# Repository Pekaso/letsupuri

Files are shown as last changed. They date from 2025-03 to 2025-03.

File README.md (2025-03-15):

# れつぷり!! letsupuri keyboard



48キー左右分離型キーボード「Let's Split」のリメイク版。

A remake of the 48 key split keyboard "Let's Split".
Left and right connection is using USB Type-C cable. And main and power circult are separated.

- 左右間をUSB-Cケーブルで接続
- PCBはメイン基板と電源基板で分離
- シリコン製ショックアブソーバーを使ったマウント

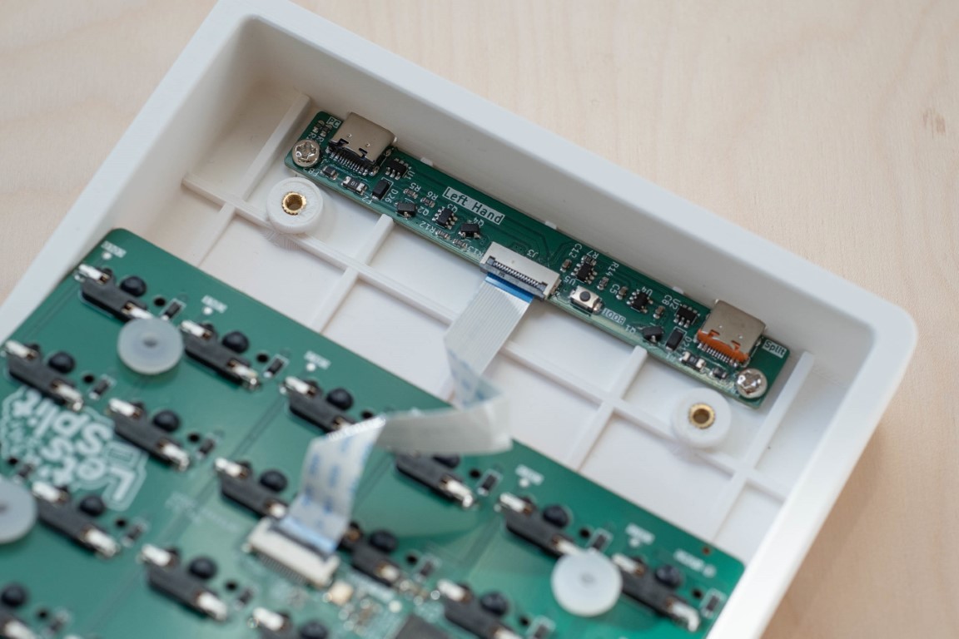
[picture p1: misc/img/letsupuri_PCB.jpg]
feature


## ビルドガイド Build Guide

- ロープロファイル版ビルドガイド(日本語版): [Low Profile Ver. Build Guide (JP)](misc/buildguide/buildguide_lowprofile_jp.md)

れつぷり!!にはCherry MX版とLow Profile版があります。ハードウェアのメイン基板はCherry MX版（PCB_main_MX）とLow Profile版（PCB_main_lowprofile）で分かれています。電源基板（PCB_power）は共通です。

"れつぷり!!" has the Cherry MX version and the Low Profile version. The main board of the hardware is divided into the Cherry MX version (PCB_main_MX) and the Low Profile version (PCB_main_lowprofile). The power supply board (PCB_power) is the same for both versions.

> [!WARNING]
> Cherry MX版のハードウェア(PCB_main_MX)は現在のところ正しく動きません。The Cherry MX version (PCB_main_MX) does not currently work properly.

## ぴくちゃ
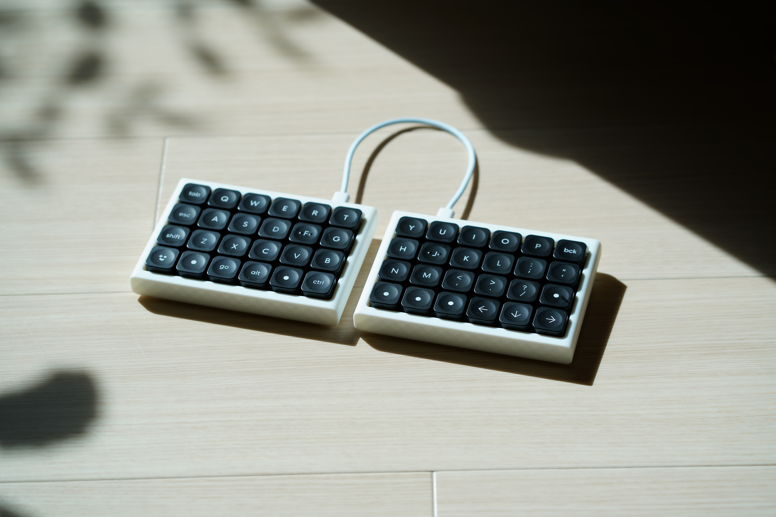
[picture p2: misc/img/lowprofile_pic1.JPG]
れつぷり!!LowProfile版

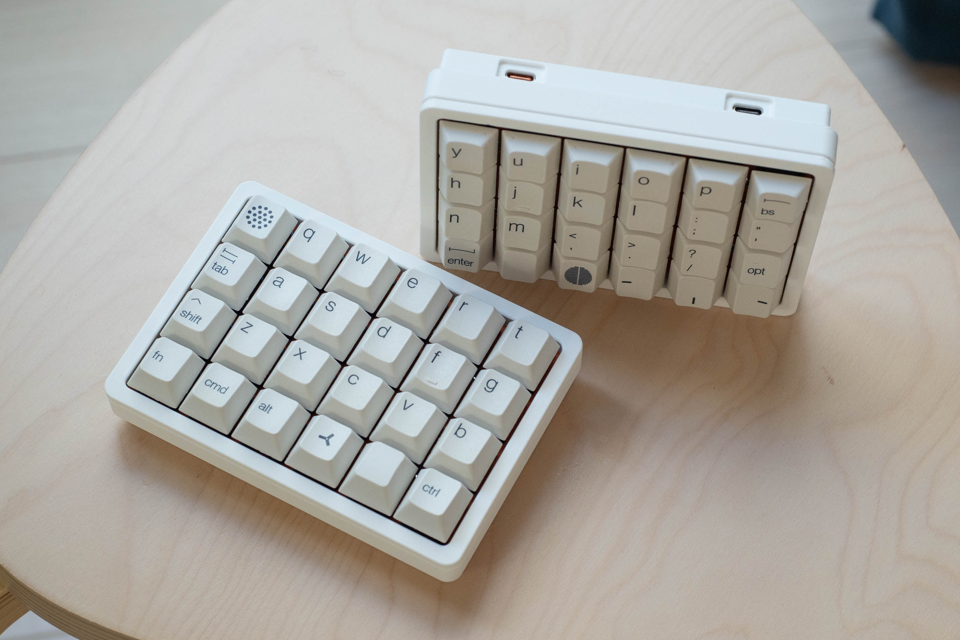
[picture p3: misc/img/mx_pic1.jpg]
れつぷり!!MX版


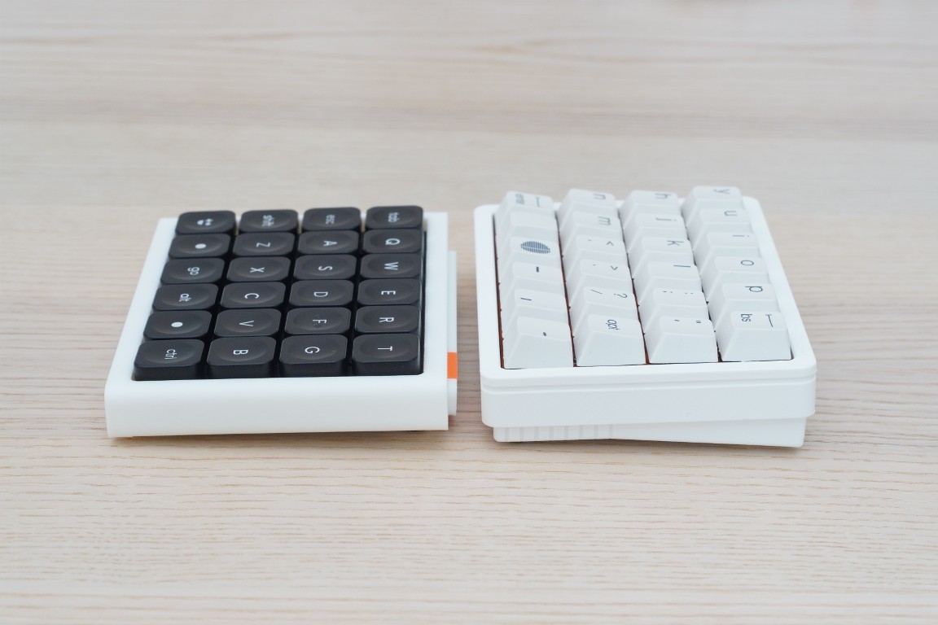
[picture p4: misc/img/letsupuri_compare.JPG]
れつぷり!!LowProfile版（左）とMX版（右）の比較


more detail at [pekaso.org](https://pekaso.org)

# License
This repository contains both hardware and firmware components, each under a different license.

- `hardware/`: Licensed under the MIT License
- `firmware/`: Licensed under the GPL License (inherited from the original repository)

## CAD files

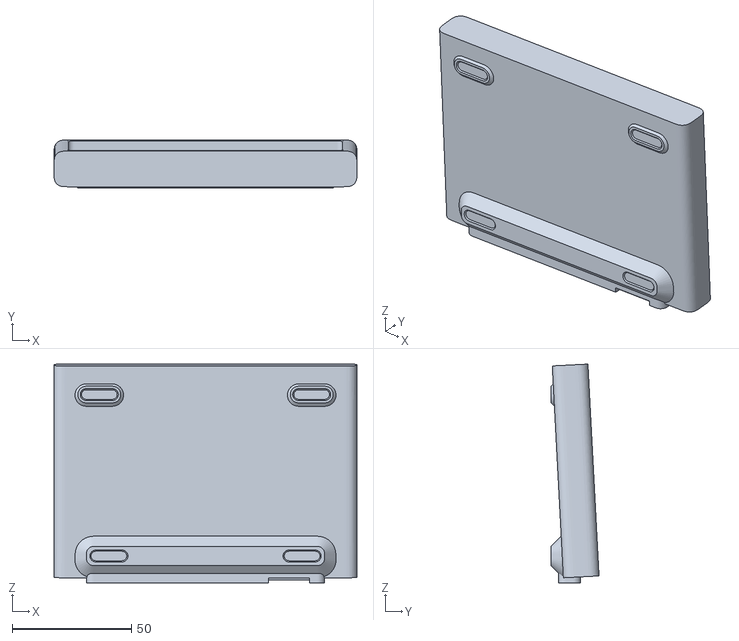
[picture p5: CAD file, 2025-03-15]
hardware/CASE/lowprofile_main.stl
127.1 x 20.2 x 91.8

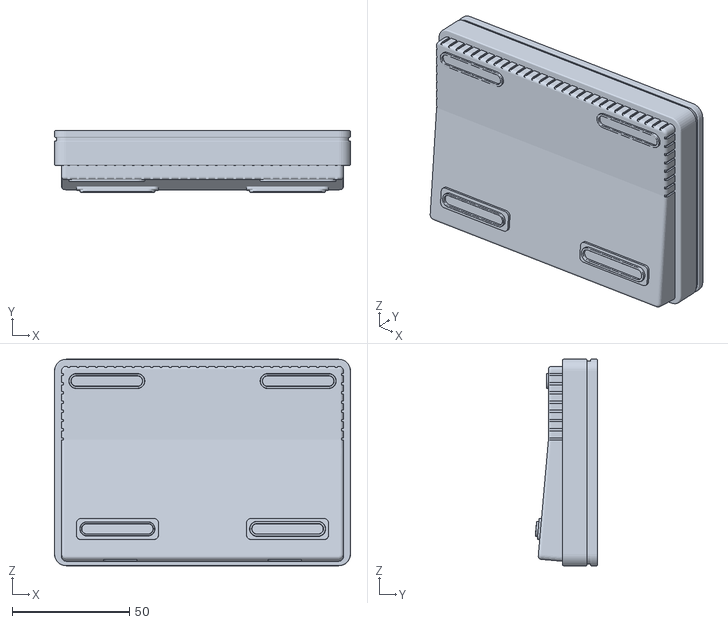
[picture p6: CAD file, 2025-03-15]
hardware/CASE/MX_main.stl
126.1 x 26.6 x 88.0

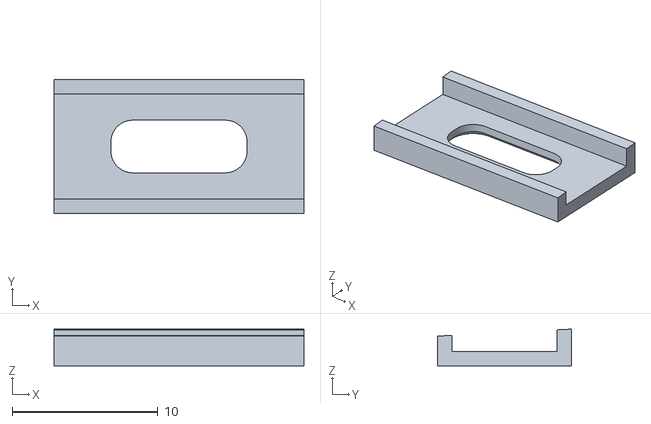
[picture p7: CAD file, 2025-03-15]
hardware/CASE/lowprofile_badge.stl
17.1 x 9.21 x 2.53

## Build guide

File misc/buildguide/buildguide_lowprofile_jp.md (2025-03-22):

# れつぷり!! Low Profile版 キット ビルドガイド

## はじめに

キットをお選びいただきありがとうございます。
組み立て前にビルドガイドと付属品リストを確認し、不足があれば連絡先までご連絡ください。

## 付属品

| 項目 | 数量 |
|---|---|
| 3Dプリントケース（試供品） | 2組 |
| れつぷり!!基板（ケースに組込済み） | 2組 |
| プレート（ケースに組込済み） | 2個 |
| ネジ（M2x8mm, ケースに組込済み） | 8個 |
| ネジ（M3x4mm, ケースに組込済み） | 4個 |
| その他（ステッカー） | 1式 |

## 購入が必要なもの

| 項目 | 数量 |
|---|---|
| キースイッチ（Choc V1/Choc V2※1） | 48個 |
| キーキャップ（スイッチに合わせたもの） | 48個 |
| USB Type-Cケーブル（左右接続用） | 1本 |
| USB Type-Cケーブル（PC接続用） | 1本 |
| ドライバー（0番） | 1本 |
| はんだごて（オプション※2） | 1式 |
| テスター（オプション※2） | 1式 |

> [!NOTE]
> 1. Choc V2は三本足のもの（赤/茶/青）には対応しません。
> 2. 基本の組み立てには不要ですが、修理などトラブルシューティングのために持っておくことをお勧めします。

## 組立方法

### 1. PCBをケースから取り外す
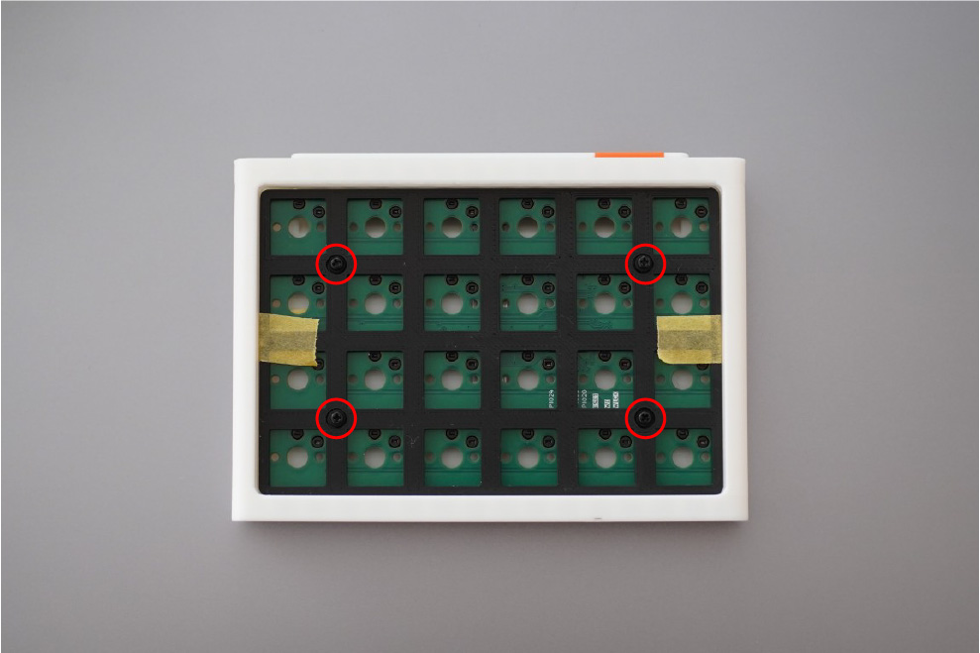
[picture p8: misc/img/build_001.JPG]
remove PCB from Case


ケースにPCBを留めているネジ（M2x8mm）４本をドライバーを使って取り外します。

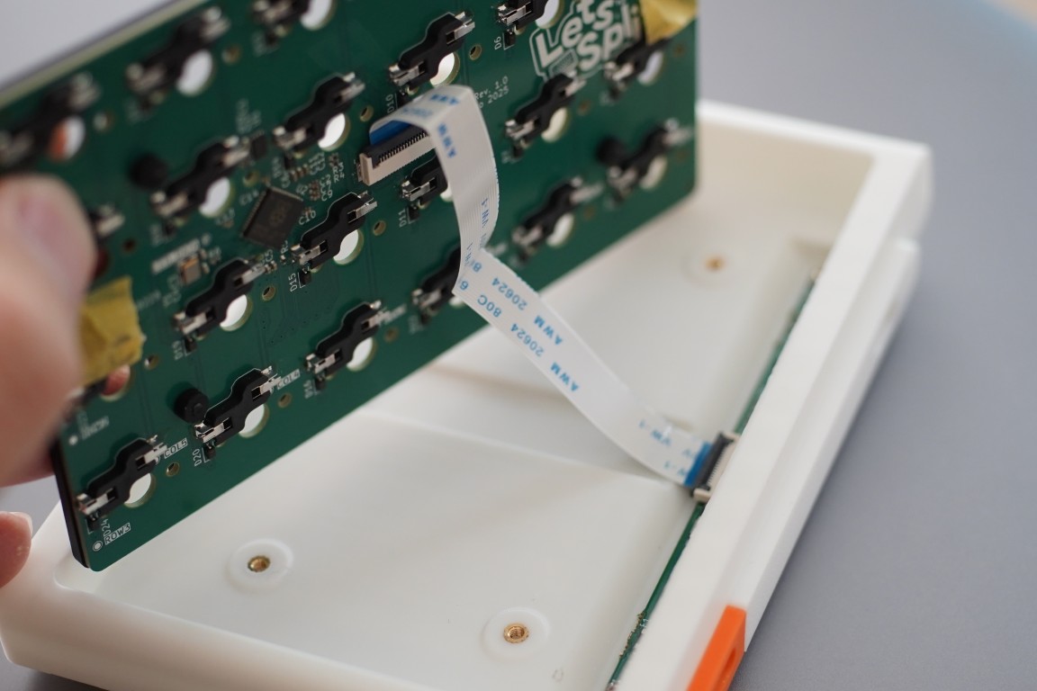
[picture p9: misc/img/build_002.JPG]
careful FFC cable


メイン基板のPCBと電源基板はフラットケーブルで接続されているため、基板を取り外す際にはケーブルを傷めないように注意してください。

PCBを取り外したらプレートを固定しているマスキングテープを取り外してください。

### 2. キースイッチを取り付ける
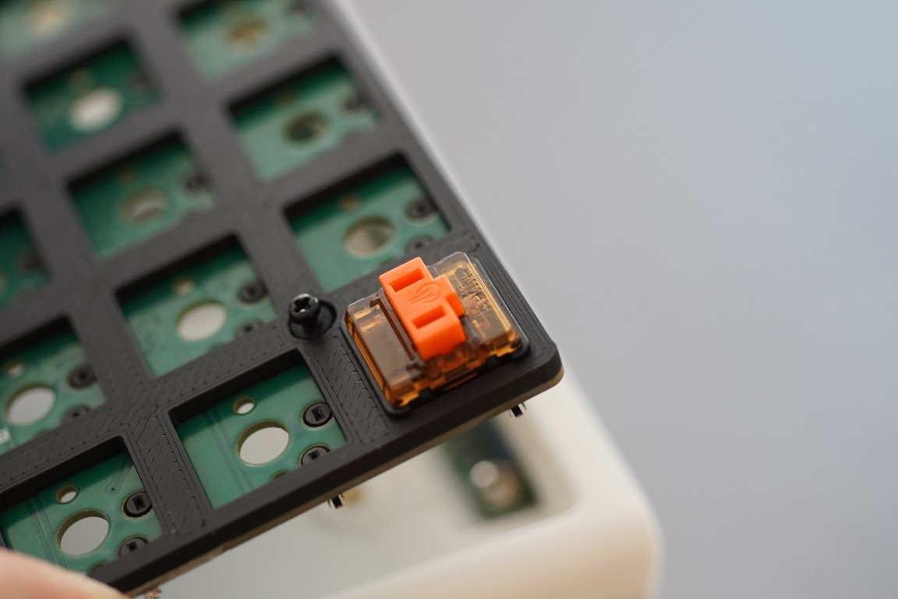
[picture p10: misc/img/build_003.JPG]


PCBにキースイッチを取り付けていきます。キースイッチの向きを確認し足が曲がっていないことに注意しながら取り付けていきます。

この時、ソケットに負担が加わらないように手を添えて行うことをお勧めします。

キースイッチを取り付ける上でフラットケーブルを取り外す必要はありません。キースイッチの取付時に引っ張るなどをして傷つけないように注意してください。

### 3. 基板とプレートをケースに固定する
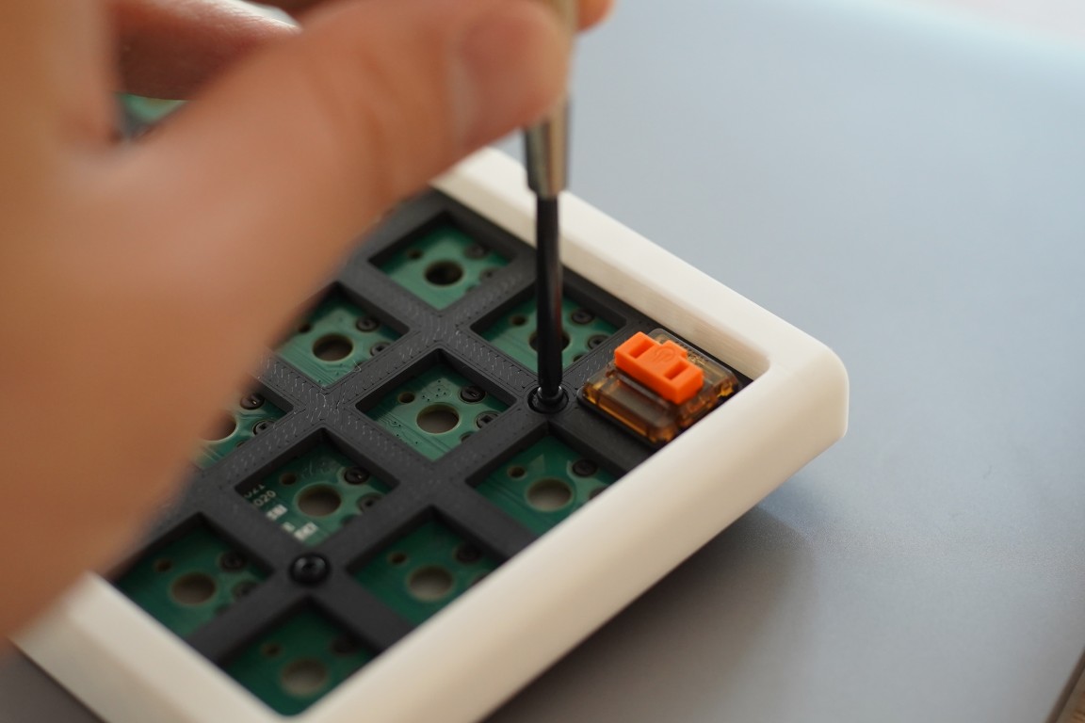
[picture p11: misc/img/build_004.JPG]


キースイッチを全て取り付けたら、PCBをケースに戻します。ゴムブッシュのマウントが有効に働くように、ネジは落ちないギリギリで軽く締めるようにしてください。

> [!CAUTION]
> **ネジを完全に締めてしまうとケースを貫通します。** 電動ドライバーなどは使用せず、指で軽く回しながら、少しでも重くなったときに止める程度が適切です。

### 4. キーキャップを取り付ける
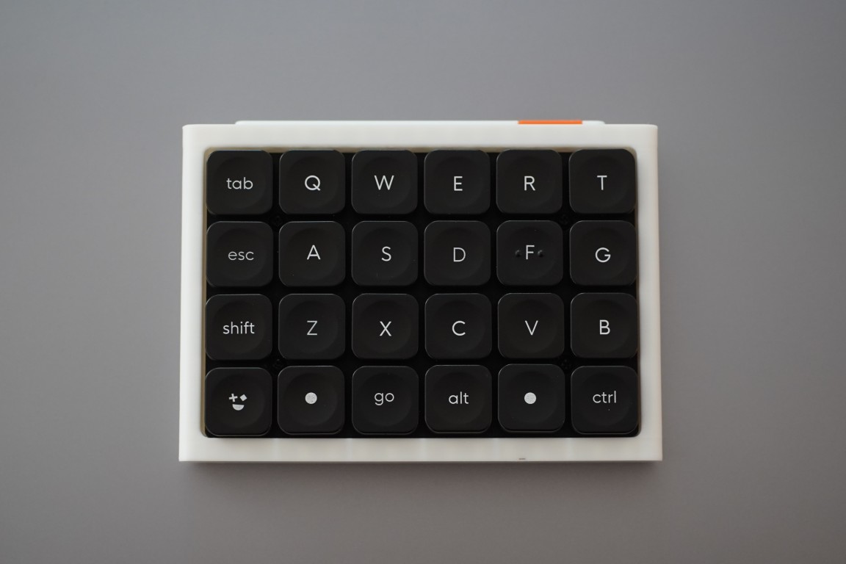
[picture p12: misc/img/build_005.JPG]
keycap


キースイッチが問題なく取付することができたらキーキャップを取り付けます。これを両手分行えば完成です！

## キーボードの接続方法
れつぷり!!は左右間接続をUSB Type-C to Type-Cケーブルで行います。左右間接続を行うケーブルはケースにオレンジ色のバッジが取り付けてあるポート同士を接続してください。

PCと接続するポートは左右どちらか一方が利用できます。利用スタイルに合わせて選んでください。

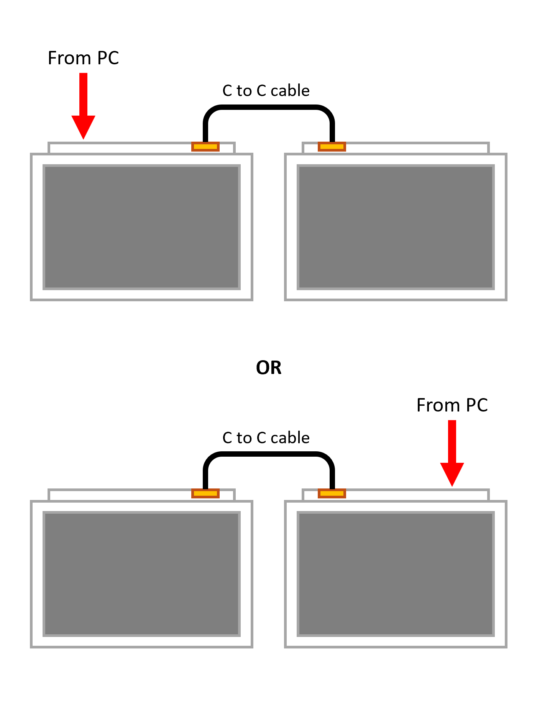
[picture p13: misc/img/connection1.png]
connection1


## （付録）キーマップ変更方法
キーマップの変更は[Vial](https://get.vial.today/)で行うことができます。キーボードを認識させた状態でデスクトップ用ツールもしくはWeb版Vialを開くことにより、各種設定変更が可能です。

## （付録）ファームウェア書き換え方法
れつぷり!!はMCUにRP2040を使用しています。ファームウェアを書き換えるためには以下の2通りの方法でブートローダーモードに入れる必要があります。

> [!NOTE]
> れつぷり!!はテスト用にファームウェアを書き込み済みの為、基本的にファームウェアを書き換える必要はありません。

### Vialからブートローダーモードに入る方法
1. れつぷり!!をPCに接続し、Vialを開いてキーマップを編集できる状態にする
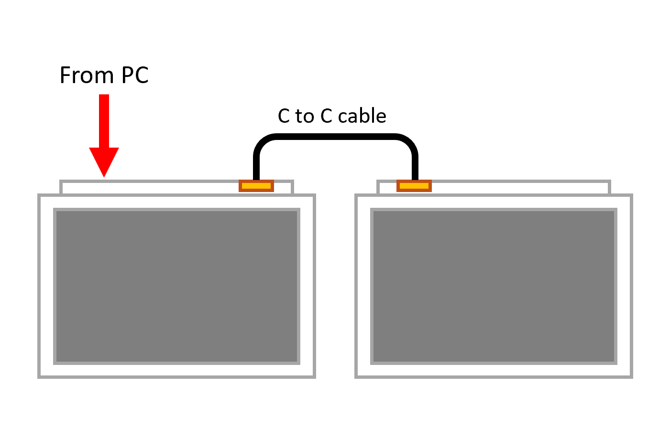
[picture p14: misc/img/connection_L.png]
connection_L

2. Vialのウィンドウ上部の"Security" -> "Reboot to Bootloader"をクリック
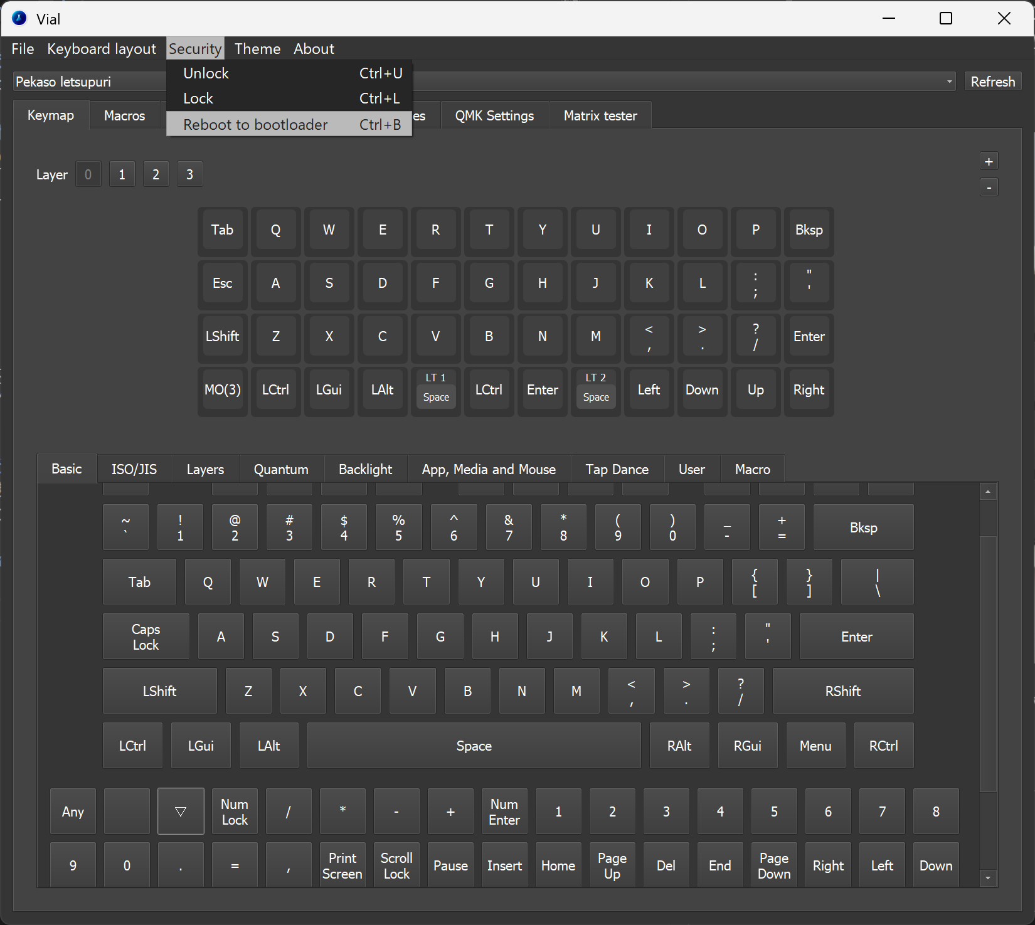
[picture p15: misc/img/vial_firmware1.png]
firmware1

3. 画面の指示にしたがって、指定されたキーをプログレスバーが100%になるまで長押しする
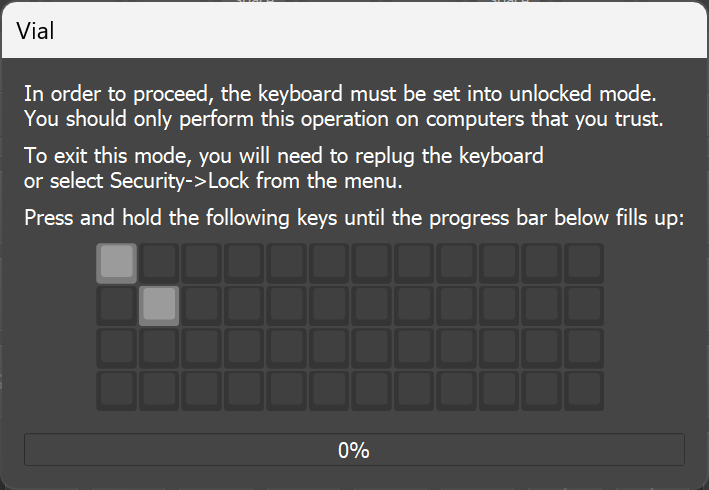
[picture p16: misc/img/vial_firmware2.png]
firmware1

4. れつぷり!!がブートローダーモードに入ると、WindowsであればExplorer上、MacならFinder上に"RPI-RP2"が出現する
bootloader1
5. ファームウェアファイル("letsupuri_vial.uf2")をRPI-RP2にドラッグアンドドロップする。自動で再起動し、キーボードとして認識します。
6. 最初にPCと繋いでいたのと反対側のポートにUSBケーブルを接続し、同じ手順を繰り返す
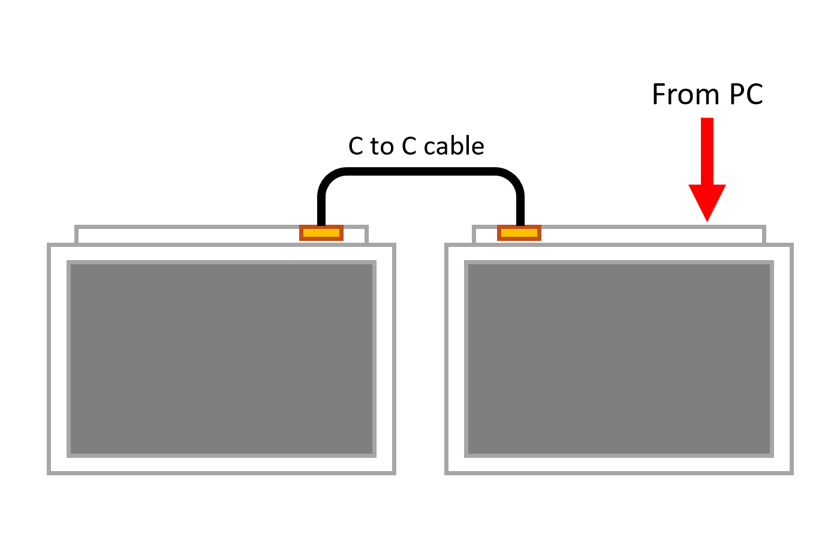
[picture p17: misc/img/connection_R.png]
connection_L


### BOOTボタンを押してブートローダーモードに入る方法
1. れつぷり!!のメイン基板のPCBを留めている４本のネジを外し、電源基板が見えるようにする。（メイン基板は取り外さないでください！）
2. 電源基板上にある"BOOT"と書かれたボタンを押しながら片手だけにUSBケーブルを接続する。
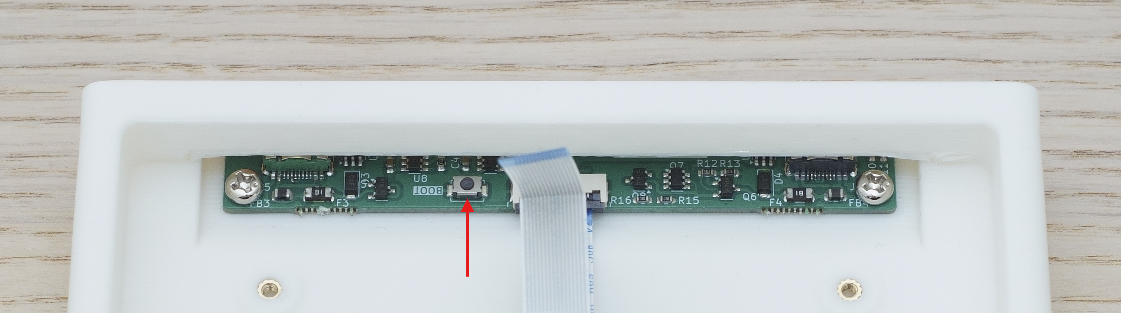
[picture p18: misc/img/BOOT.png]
BOOT_button

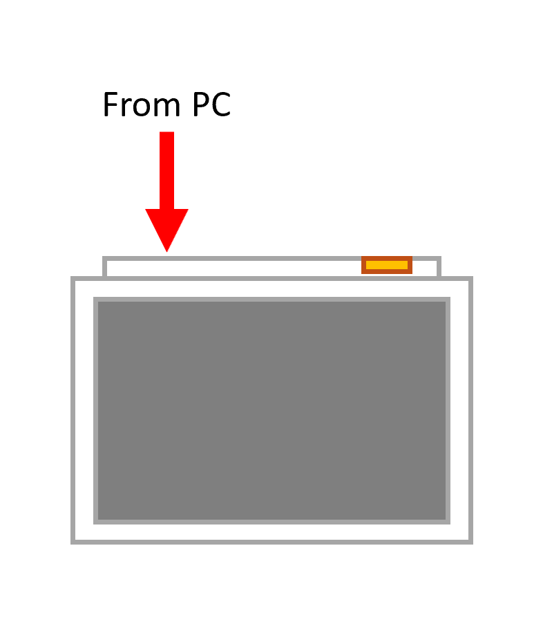
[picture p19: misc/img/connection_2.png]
connection_2

4. れつぷり!!がブートローダーモードに入ると、WindowsであればExplorer上、MacならFinder上に"RPI-RP2"が出現する
bootloader1
5. ファームウェアファイル("letsupuri_vial.uf2")をRPI-RP2にドラッグアンドドロップする。自動で再起動し、キーボードとして認識します。
6. もう一方の片手分に大して同じ手順を繰り返す

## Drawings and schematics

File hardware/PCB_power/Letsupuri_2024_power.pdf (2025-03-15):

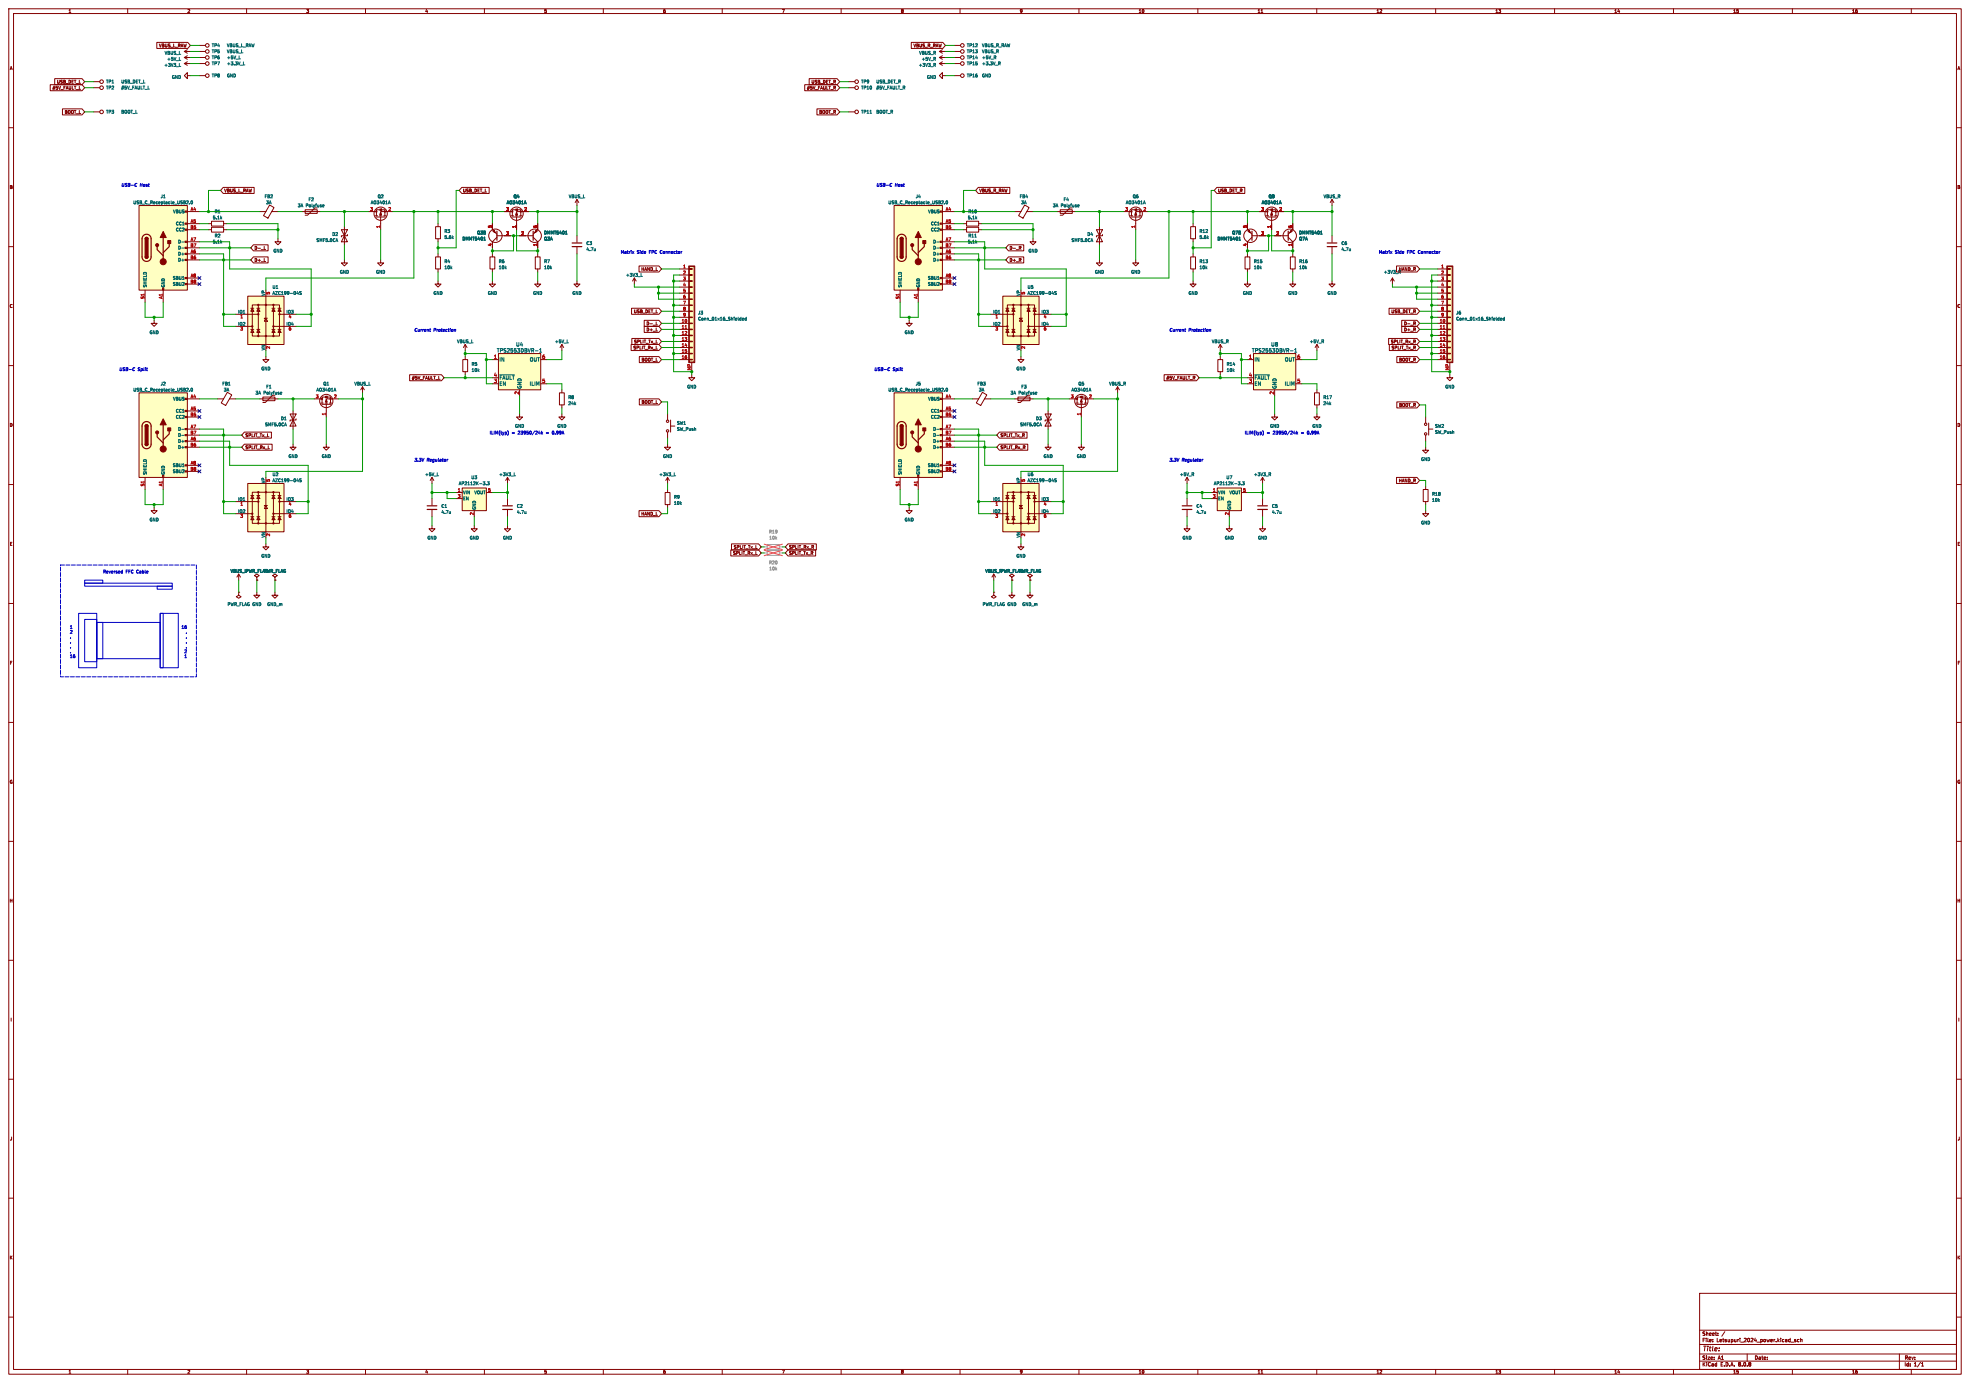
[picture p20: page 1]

2 EN 3 VOUT 5 U3 AP2112K-3.3 GND +3V3_L A1 VBUS A4 CC1 A5 D+ A6 D- A7 SBU1 A8 CC2 B5 D+ B6 D- B7 SBU2 B8 SHIELD S1

Id: 1/1 Title: File: Letsupuri_2024_power.kicad_sch Sheet: /

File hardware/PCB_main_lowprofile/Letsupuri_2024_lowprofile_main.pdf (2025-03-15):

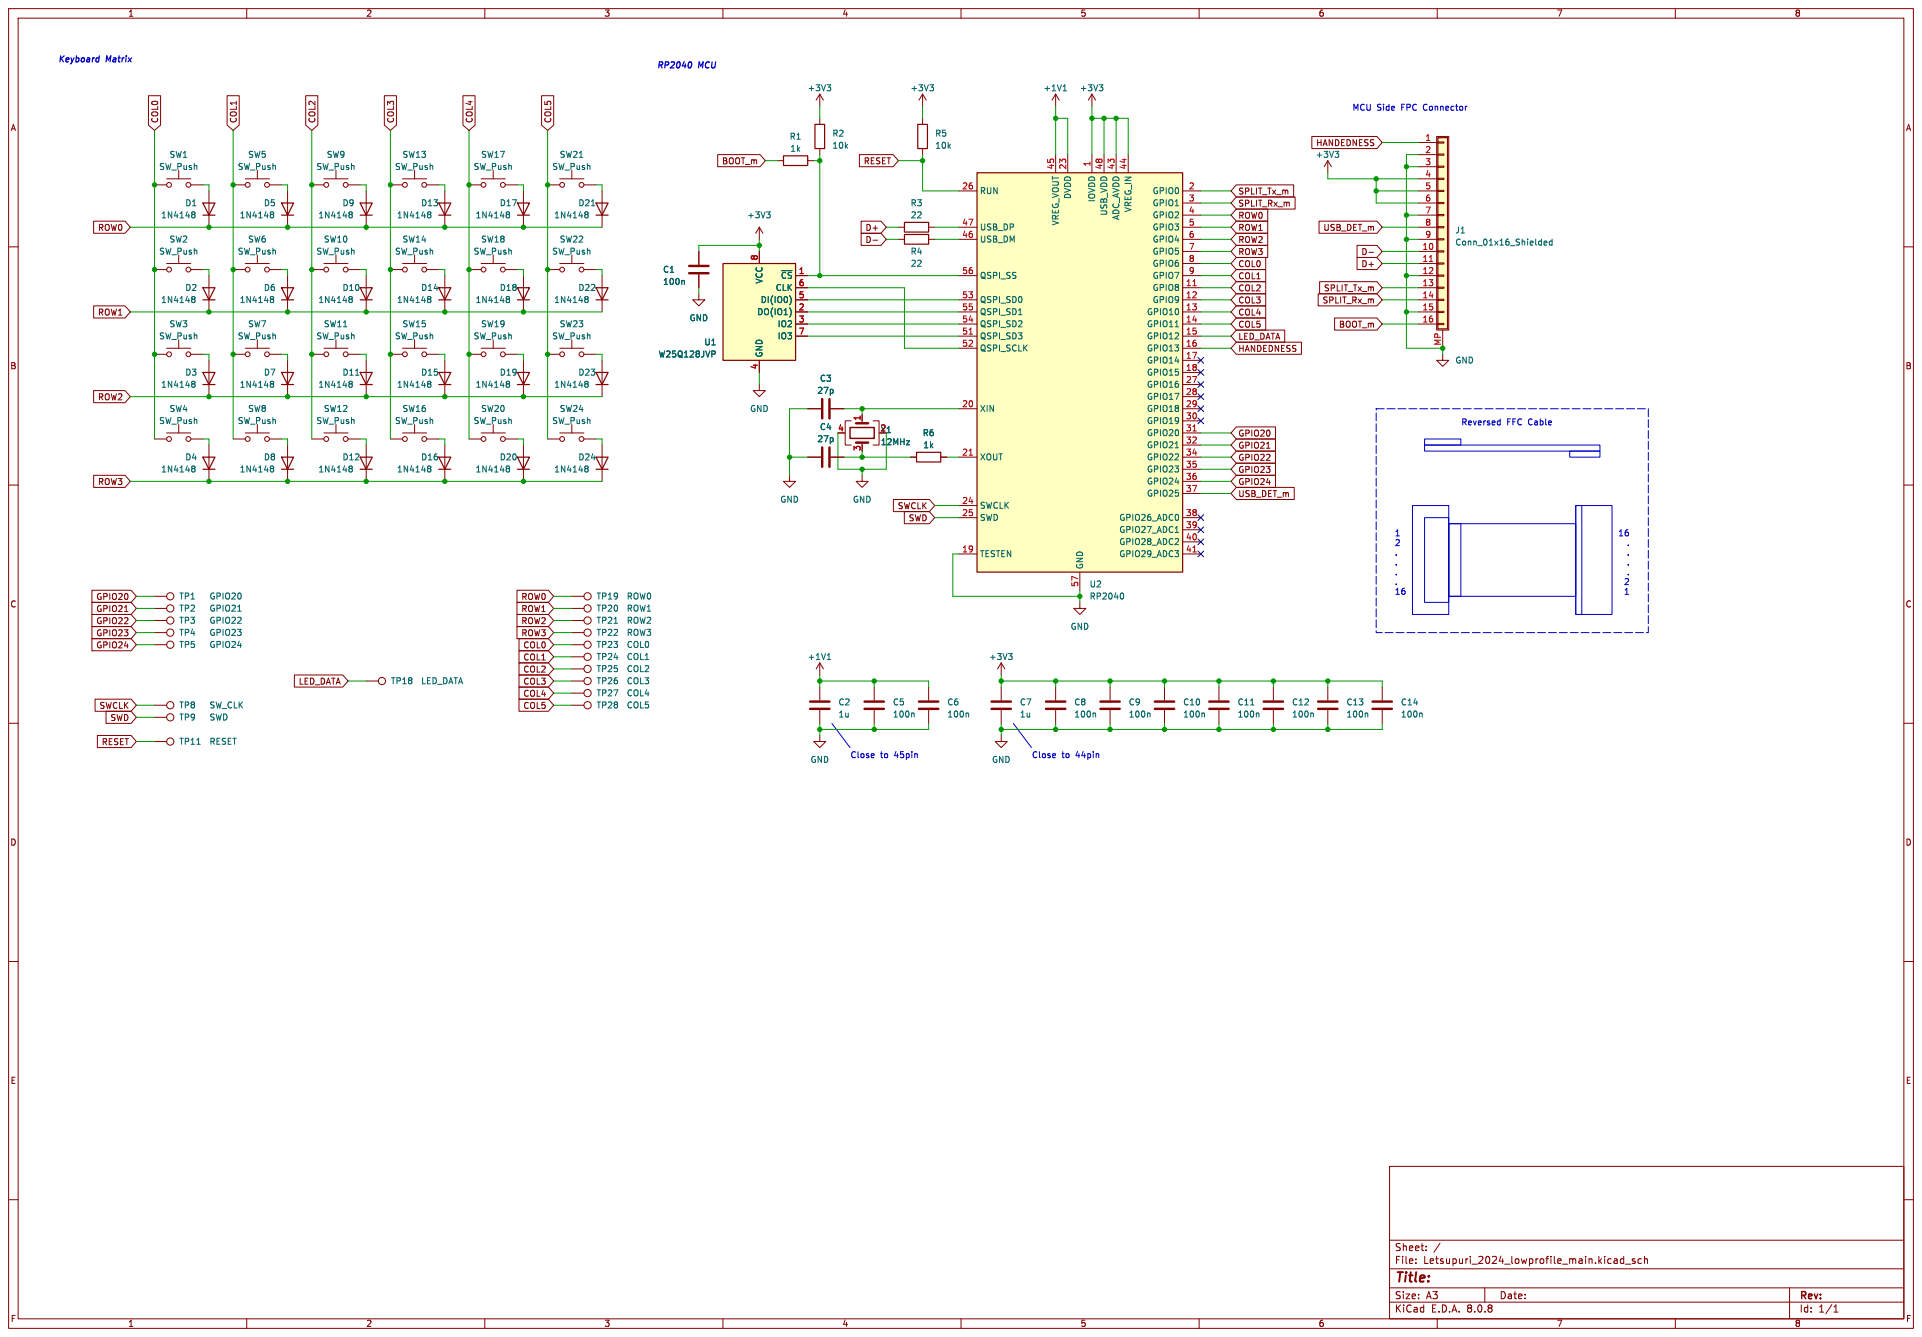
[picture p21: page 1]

1 GPIO8 11 GPIO9 12 GPIO10 13 GPIO11 14 GPIO12 15 GPIO13 16 GPIO14 17 GPIO15 18 TESTEN 19 GPIO0 2 XIN 20 XOUT 21 DVDD 23 SWCLK 24 SWD 25 RUN 26 GPIO16 27 GPIO17 28 GPIO18 29 GPIO1 3 GPIO19 30 GPIO20 31 GPIO21 32 GPIO22 34 GPIO23 35 GPIO24 36 GPIO25 37 GPIO26_ADC0 38 GPIO27_ADC1 39 GPIO2 4 GPIO28_ADC2 40 GPIO29_ADC3 41 ADC_AVDD 43 VREG_IN 44 VREG_VOUT 45 USB_DM 46 USB_DP 47 USB_VDD 48 GPIO3 5 QSPI_SD3 51 QSPI_SCLK 52 QSPI_SD0 53 QSPI_SD2 54 QSPI_SD1 55 QSPI_SS 56 GND 57 GPIO4 6 GPIO5 7 GPIO6 8 GPIO7 9 U2 RP2040 C8

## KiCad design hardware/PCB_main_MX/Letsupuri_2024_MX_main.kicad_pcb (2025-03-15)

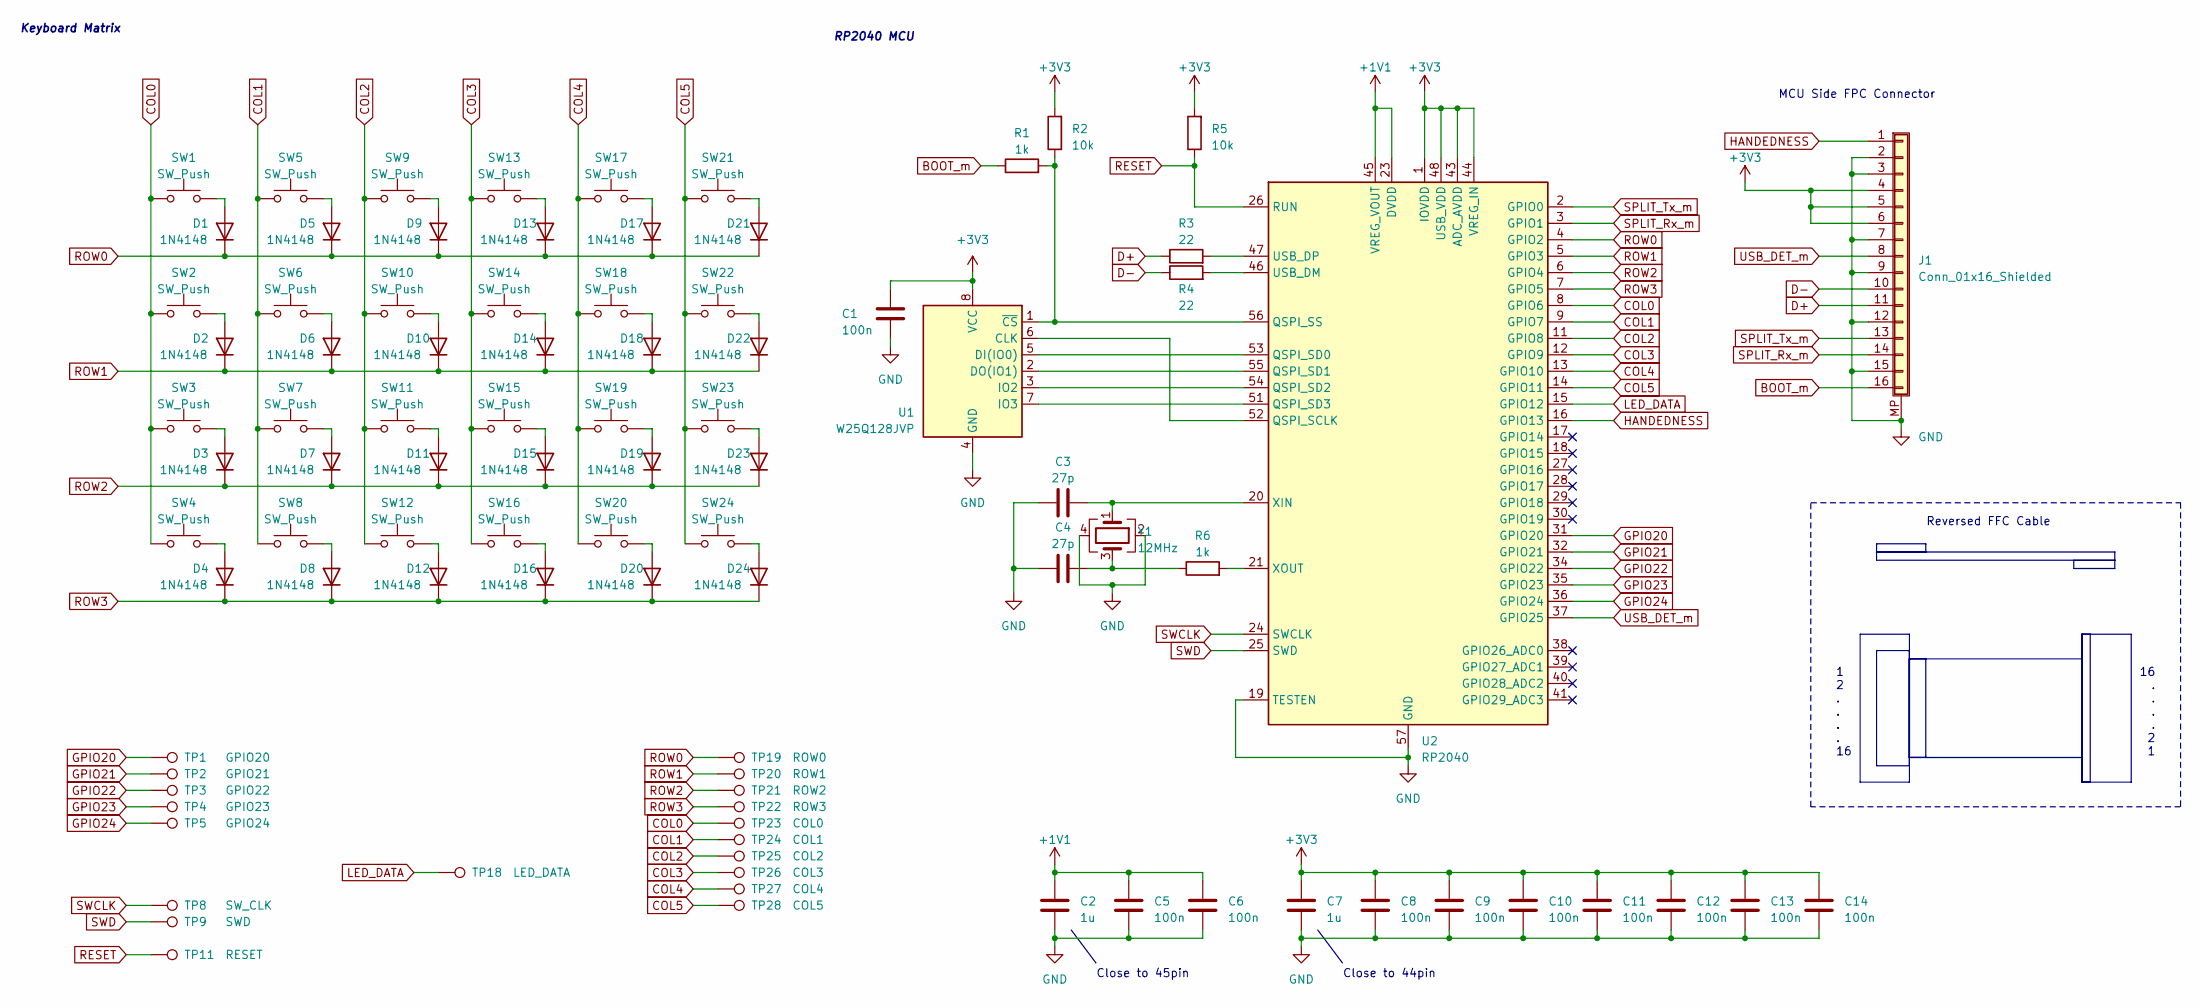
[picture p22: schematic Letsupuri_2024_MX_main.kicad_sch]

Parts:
C1, C5, C6, C8, C9, C10, C11, C12, C13, C14: 100n; C_0402_1005Metric; LCSC C1591
C2, C7: 1u; C_0402_1005Metric; LCSC C15849
C3, C4: 27p; C_0402_1005Metric; LCSC C107045
D1, D2, D3, D4, D5, D6, D7, D8, D9, D10, D11, D12, D13, D14, D15, D16, D17, D18, D19, D20, D21, D22, D23, D24: 1N4148; D_SOD-323; LCSC C81598
J1: Conn_01x16_Shielded; TE_1-1734839-6_1x16-1MP_P0.5mm_Horizontal
R1, R6: 1k; R_0402_1005Metric; LCSC C21190
R2, R5: 10k; R_0402_1005Metric; LCSC C25804
R3, R4: 22; R_0402_1005Metric; LCSC C23345
SW1, SW2, SW3, SW4, SW5, SW6, SW7, SW8, SW9, SW10, SW11, SW12, SW13, SW14, SW15, SW16, SW17, SW18, SW19, SW20, SW21, SW22, SW23, SW24: SW_Push; SW_Hotswap_Kailh_Choc_V1V2_1.00u
TP1: GPIO20; TestPoint_Pad_D1.0mm
TP2: GPIO21; TestPoint_Pad_D1.0mm
TP3: GPIO22; TestPoint_Pad_D1.0mm
TP4: GPIO23; TestPoint_Pad_D1.0mm
TP5: GPIO24; TestPoint_Pad_D1.0mm
TP8: SW_CLK; TestPoint_Pad_D1.0mm
TP9: SWD; TestPoint_Pad_D1.0mm
TP11: RESET; TestPoint_Pad_D1.0mm
TP18: LED_DATA; TestPoint_Pad_D1.0mm
TP19: ROW0; TestPoint_Pad_D1.0mm
TP20: ROW1; TestPoint_Pad_D1.0mm
TP21: ROW2; TestPoint_Pad_D1.0mm
TP22: ROW3; TestPoint_Pad_D1.0mm
TP23: COL0; TestPoint_Pad_D1.0mm
TP24: COL1; TestPoint_Pad_D1.0mm
TP25: COL2; TestPoint_Pad_D1.0mm
TP26: COL3; TestPoint_Pad_D1.0mm
TP27: COL4; TestPoint_Pad_D1.0mm
TP28: COL5; TestPoint_Pad_D1.0mm
U1: W25Q128JVP; Winbond_USON-8-1EP_3x2mm_P0.5mm_EP0.2x1.6mm; LCSC C190862
U2: RP2040; QFN-56-1EP_7x7mm_P0.4mm_EP3.2x3.2mm; LCSC C2040
Y1: 12MHz; Crystal_SMD_3225-4Pin_3.2x2.5mm; LCSC C9002

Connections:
+1V1: C2.2, C5.2, C6.2, U2.23 (DVDD), U2.45 (VREG_VOUT), U2.50 (DVDD); also elsewhere on the board
+3V3: C1.2, C7.2, C8.2, C9.2, C10.2, C11.2, C12.2, C13.2, C14.2, J1.4, J1.5, J1.6, R2.2, R5.2, U1.8 (VCC), U2.1 (IOVDD), U2.10 (IOVDD), U2.22 (IOVDD), U2.33 (IOVDD), U2.42 (IOVDD), U2.43 (ADC_AVDD), U2.44 (VREG_IN), U2.48 (USB_VDD), U2.49 (IOVDD)
BOOT_m: J1.16, R1.1
COL0: SW1.1, SW2.1, SW3.1, SW4.1, TP23.1, U2.8 (GPIO6)
COL1: SW5.1, SW6.1, SW7.1, SW8.1, TP24.1, U2.9 (GPIO7)
COL2: SW9.1, SW10.1, SW11.1, SW12.1, TP25.1, U2.11 (GPIO8)
COL3: SW13.1, SW14.1, SW15.1, SW16.1, TP26.1, U2.12 (GPIO9)
COL4: SW17.1, SW18.1, SW19.1, SW20.1, TP27.1, U2.13 (GPIO10)
COL5: SW21.1, SW22.1, SW23.1, SW24.1, TP28.1, U2.14 (GPIO11)
D+: J1.11, R3.1
D-: J1.10, R4.1
GND: C1.1, C2.1, C3.1, C4.1, C5.1, C6.1, C7.1, C8.1, C9.1, C10.1, C11.1, C12.1, C13.1, C14.1, J1.2, J1.3, J1.7, J1.9, J1.12, J1.15, J1.MP (Shield), U1.4 (GND), U2.19 (TESTEN), U2.57 (GND), Y1.2, Y1.4
GPIO20: TP1.1, U2.31 (GPIO20)
GPIO21: TP2.1, U2.32 (GPIO21)
GPIO22: TP3.1, U2.34 (GPIO22)
GPIO23: TP4.1, U2.35 (GPIO23)
GPIO24: TP5.1, U2.36 (GPIO24)
HANDEDNESS: J1.1, U2.16 (GPIO13)
LED_DATA: TP18.1, U2.15 (GPIO12)
unnamed: C4.2, R6.1, Y1.3
unnamed: D1.2 (A), SW1.2
unnamed: D2.2 (A), SW2.2
unnamed: D3.2 (A), SW3.2
unnamed: D4.2 (A), SW4.2
unnamed: D5.2 (A), SW5.2
unnamed: D6.2 (A), SW6.2
unnamed: D7.2 (A), SW7.2
unnamed: D8.2 (A), SW8.2
unnamed: D9.2 (A), SW9.2
unnamed: D10.2 (A), SW10.2
unnamed: D11.2 (A), SW11.2
unnamed: D12.2 (A), SW12.2
unnamed: D13.2 (A), SW13.2
unnamed: D14.2 (A), SW14.2
unnamed: D15.2 (A), SW15.2
unnamed: D16.2 (A), SW16.2
unnamed: D17.2 (A), SW17.2
unnamed: D18.2 (A), SW18.2
unnamed: D19.2 (A), SW19.2
unnamed: D20.2 (A), SW20.2
unnamed: D21.2 (A), SW21.2
unnamed: D22.2 (A), SW22.2
unnamed: D23.2 (A), SW23.2
unnamed: D24.2 (A), SW24.2
unnamed: U1.6 (CLK), U2.52 (QSPI_SCLK)
unnamed: U1.5 (DI(IO0)), U2.53 (QSPI_SD0)
unnamed: U1.2 (DO(IO1)), U2.55 (QSPI_SD1)
unnamed: U1.3 (IO2), U2.54 (QSPI_SD2)
unnamed: U1.7 (IO3), U2.51 (QSPI_SD3)
unnamed: R1.2, R2.1, U1.1 (~CS), U2.56 (QSPI_SS)
unnamed: R4.2, U2.46 (USB_DM)
unnamed: R3.2, U2.47 (USB_DP)
unnamed: C3.2, U2.20 (XIN), Y1.1
unnamed: R6.2, U2.21 (XOUT)
RESET: R5.1, TP11.1, U2.26 (RUN)
ROW0: D1.1 (K), D5.1 (K), D9.1 (K), D13.1 (K), D17.1 (K), D21.1 (K), TP19.1, U2.4 (GPIO2)
ROW1: D2.1 (K), D6.1 (K), D10.1 (K), D14.1 (K), D18.1 (K), D22.1 (K), TP20.1, U2.5 (GPIO3)
ROW2: D3.1 (K), D7.1 (K), D11.1 (K), D15.1 (K), D19.1 (K), D23.1 (K), TP21.1, U2.6 (GPIO4)
ROW3: D4.1 (K), D8.1 (K), D12.1 (K), D16.1 (K), D20.1 (K), D24.1 (K), TP22.1, U2.7 (GPIO5)
SPLIT_Rx_m: J1.14, U2.3 (GPIO1)
SPLIT_Tx_m: J1.13, U2.2 (GPIO0)
SWCLK: TP8.1, U2.24 (SWCLK)
SWD: TP9.1, U2.25 (SWD)
USB_DET_m: J1.8, U2.37 (GPIO25)

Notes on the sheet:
1 2 . . . . 16
RP2040 MCU
Close to 44pin
Keyboard Matrix
MCU Side FPC Connector
Reversed FFC Cable
Close to 45pin
16 . . . . 2 1

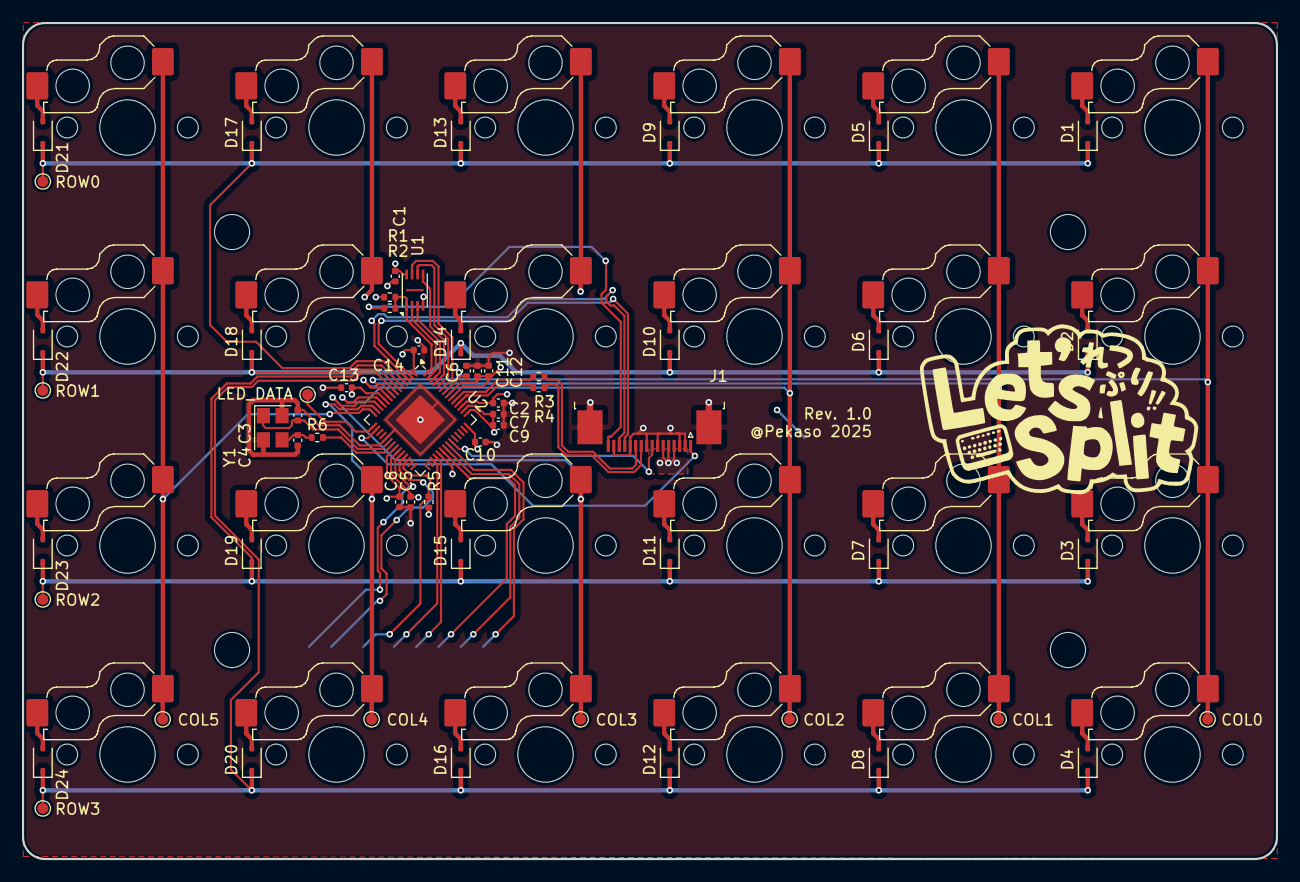
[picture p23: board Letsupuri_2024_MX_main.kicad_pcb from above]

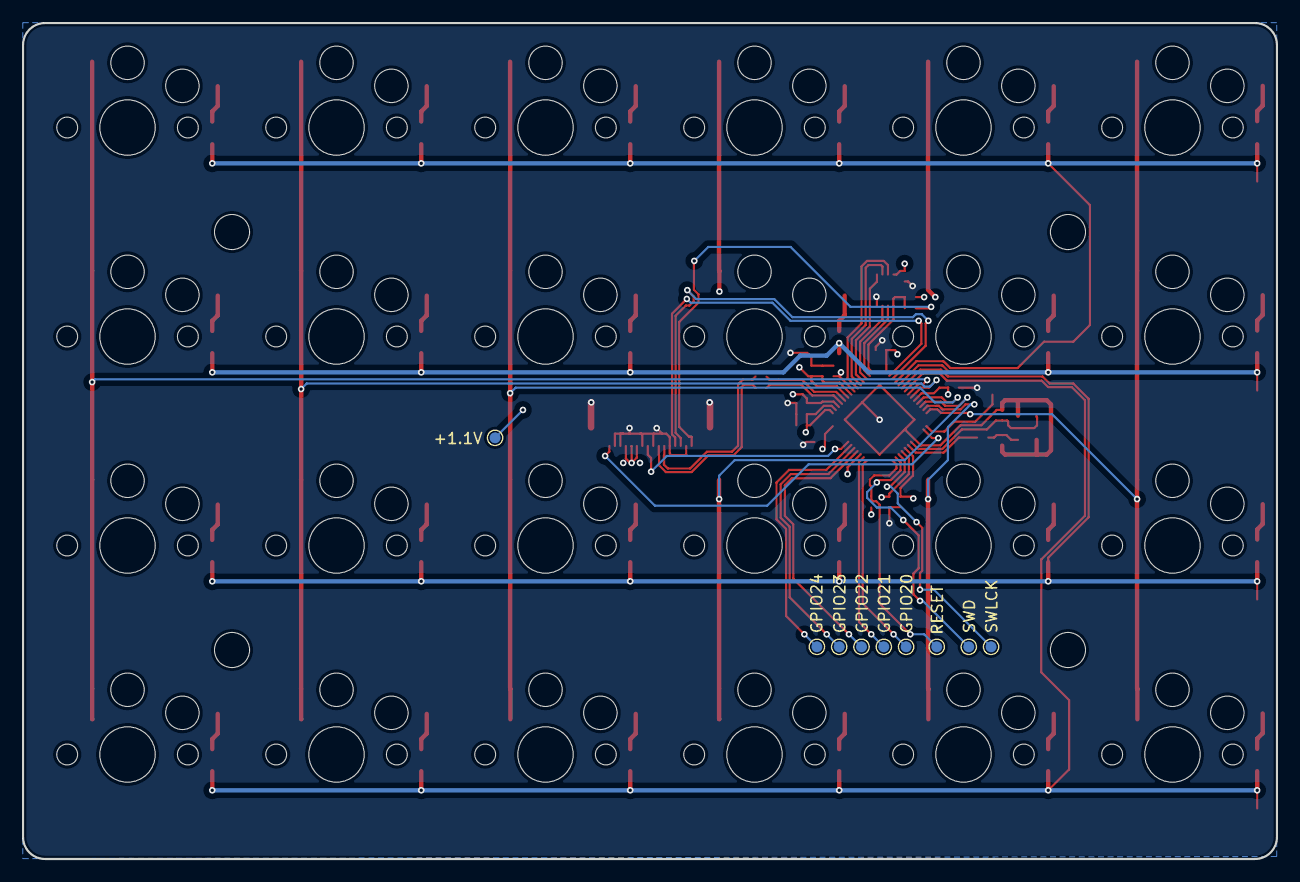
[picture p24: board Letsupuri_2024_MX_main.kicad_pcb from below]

Board: 4 copper layers, 114.3 x 76.2 mm, 92 parts (33 on the bottom side), 64 nets.

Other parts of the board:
TP16: +1.1V_L; TestPoint_Pad_D1.0mm

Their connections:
+1V1: TP16.1; also elsewhere on the board

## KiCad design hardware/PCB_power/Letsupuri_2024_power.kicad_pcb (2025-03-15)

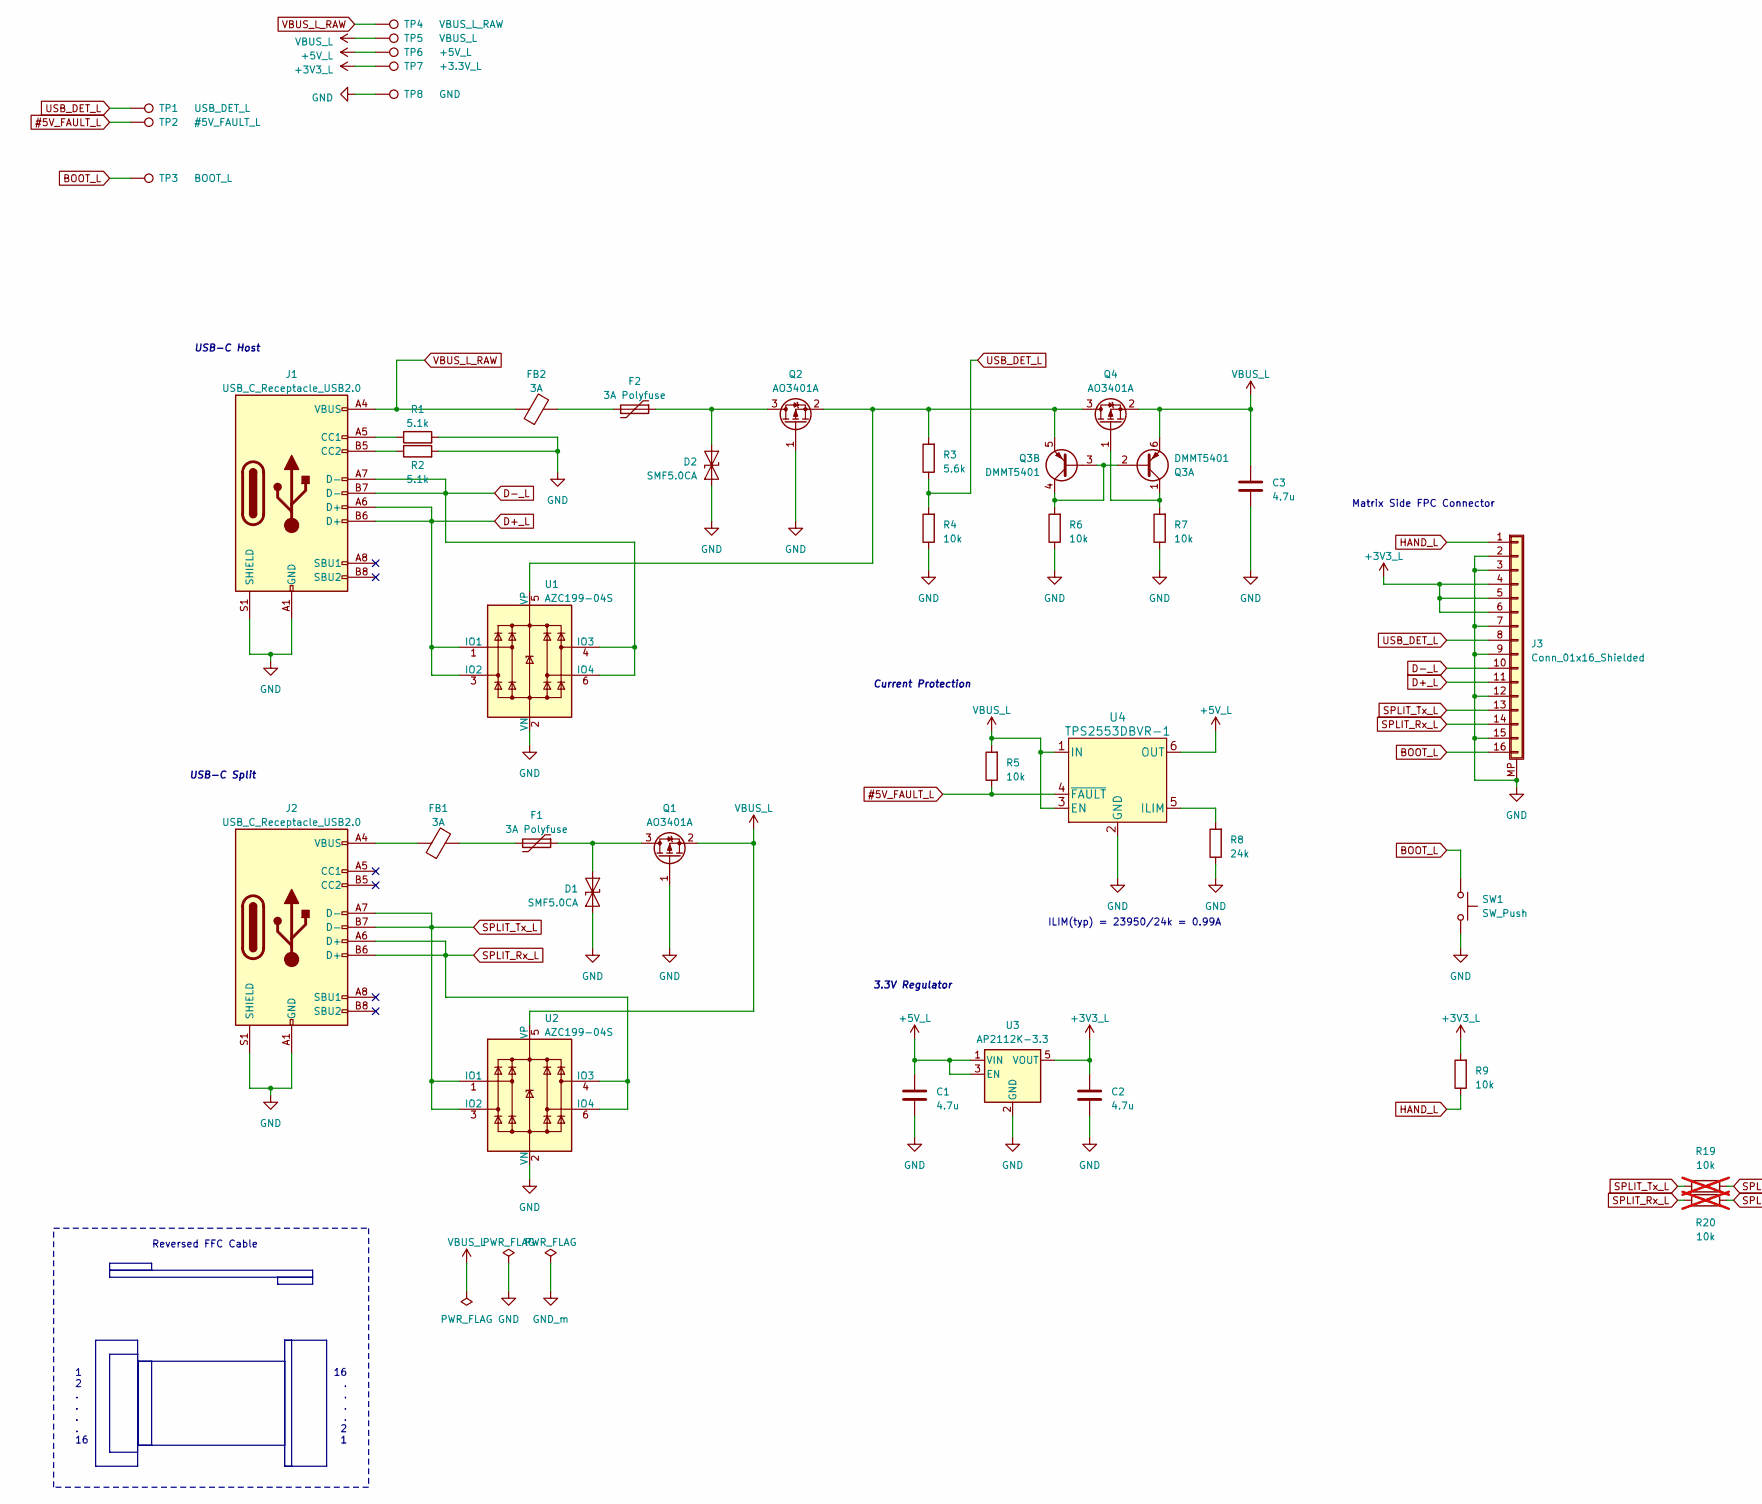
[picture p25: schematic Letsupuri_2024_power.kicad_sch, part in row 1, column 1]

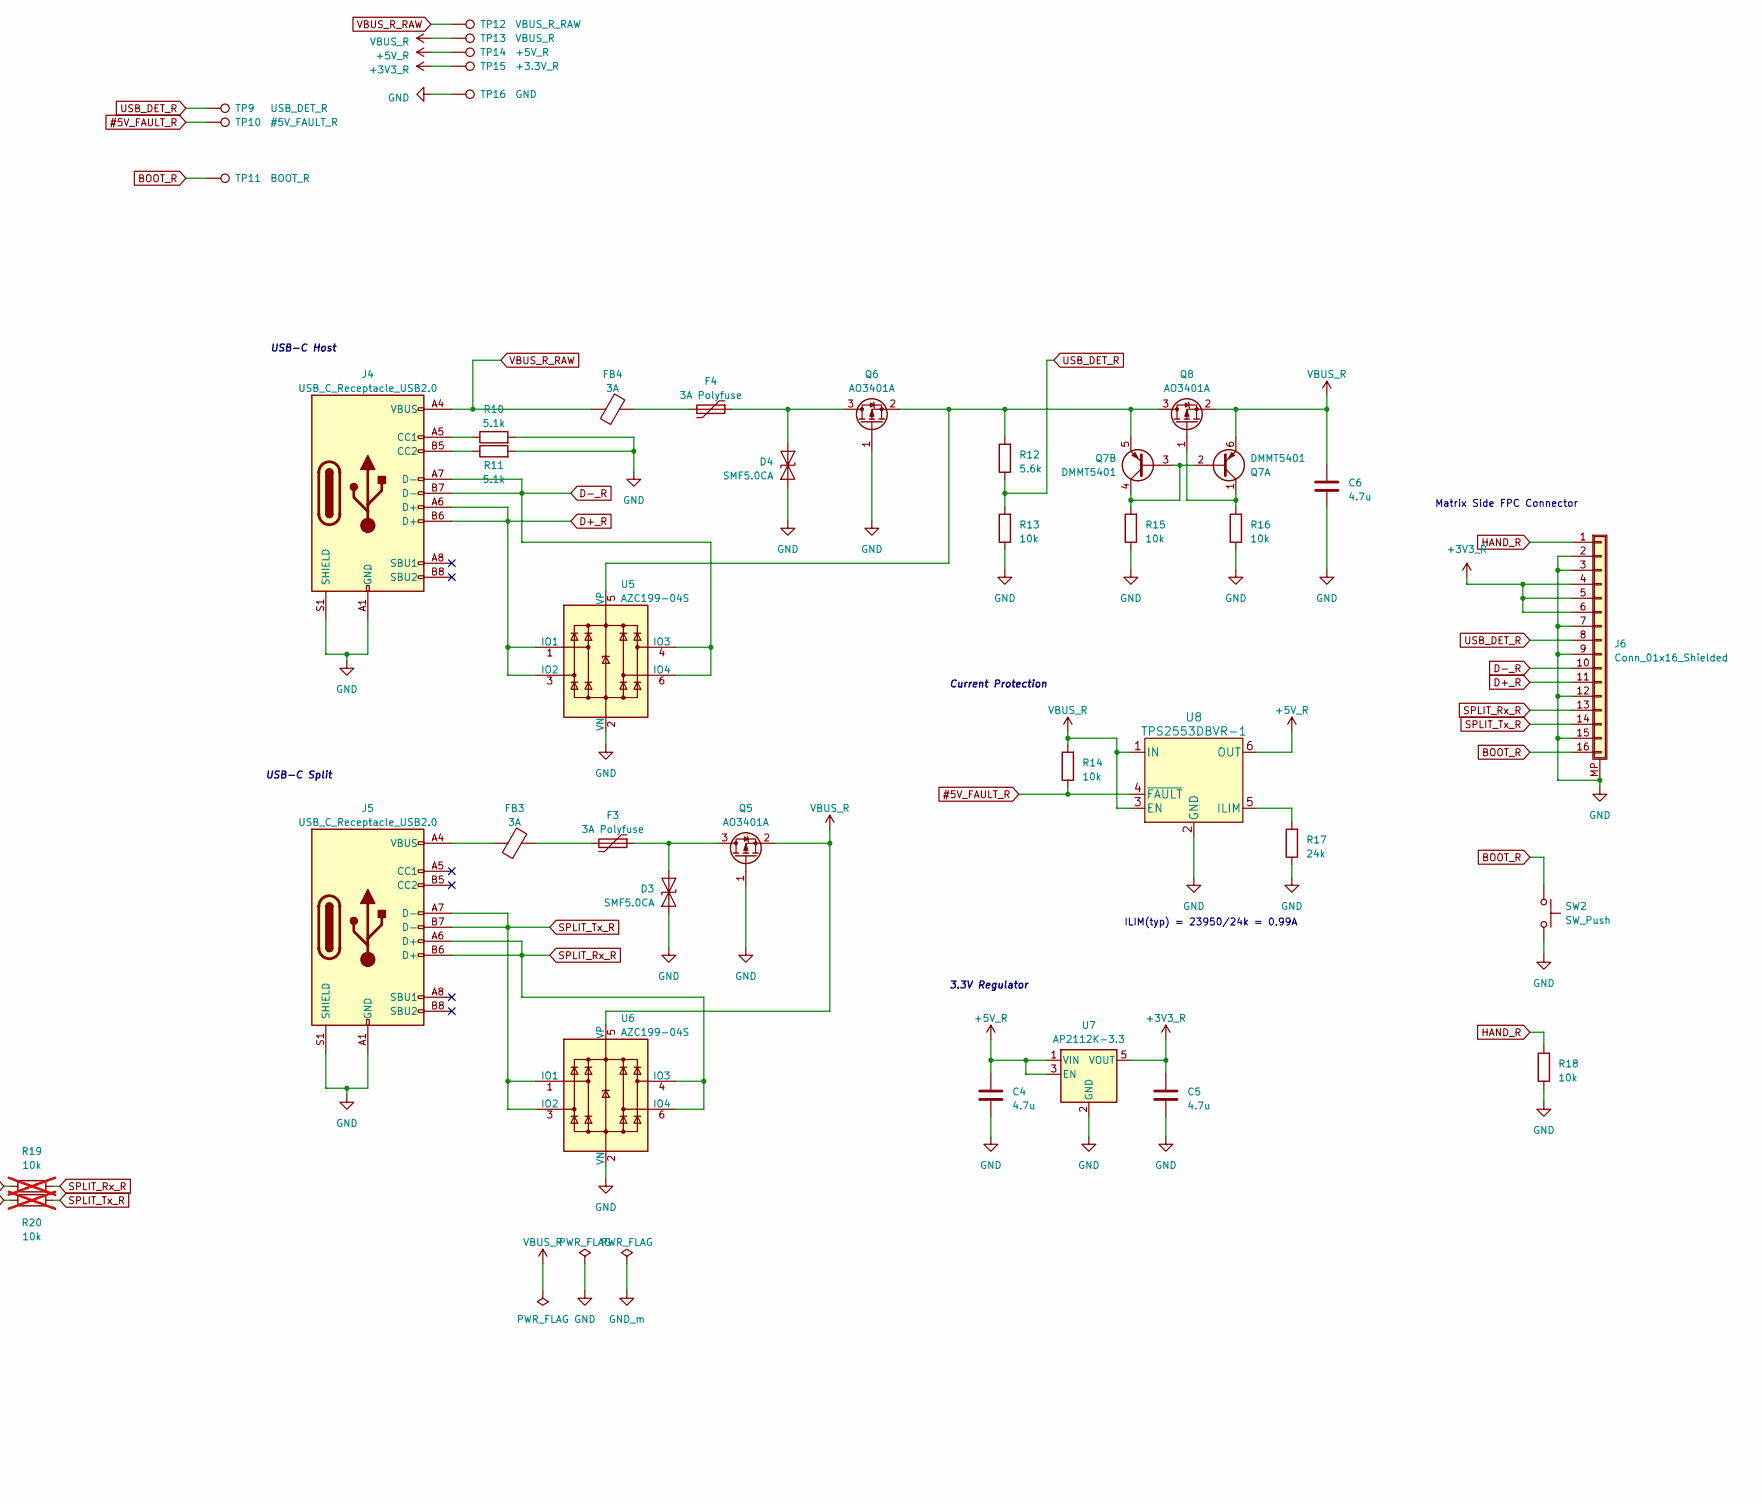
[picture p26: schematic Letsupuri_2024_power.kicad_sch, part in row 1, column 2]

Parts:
C1, C2, C3, C4, C5, C6: 4.7u; C_0603_1608Metric; LCSC C19666
D1, D2, D3, D4: SMF5.0CA; D_SOD-123; LCSC C908214
F1, F2, F3, F4: 3A Polyfuse; C_1206_3216Metric; LCSC C3020147
FB1, FB2, FB3, FB4: 3A; C_0805_2012Metric; LCSC C142054
J1, J2, J4, J5: USB_C_Receptacle_USB2.0; USB_C_Receptacle_HRO_TYPE-C-31-M-12
J3, J6: Conn_01x16_Shielded; TE_1-1734839-6_1x16-1MP_P0.5mm_Horizontal
Q1, Q2, Q4, Q5, Q6, Q8: AO3401A; SOT-23; LCSC C15127
Q3, Q7: DMMT5401; SOT-23-6; LCSC C154733
R1, R2, R10, R11: 5.1k; R_0603_1608Metric; LCSC C23186
R3, R12: 5.6k; R_0603_1608Metric; LCSC C23189
R4, R5, R6, R7, R9, R13, R14, R15, R16, R18: 10k; R_0603_1608Metric; LCSC C25804
R8, R17: 24k; R_0603_1608Metric; LCSC C23352
R19, R20: 10k; R_0603_1608Metric; LCSC C25804; not fitted
SW1, SW2: SW_Push; TS-1088-AR02016; LCSC C720477
TP1: USB_DET_L; TestPoint_Pad_D1.0mm
TP2: #5V_FAULT_L; TestPoint_Pad_D1.0mm
TP3: BOOT_L; TestPoint_Pad_D1.0mm
TP4: VBUS_L_RAW; TestPoint_Pad_D1.0mm
TP5: VBUS_L; TestPoint_Pad_D1.0mm
TP6: +5V_L; TestPoint_Pad_D1.0mm
TP7: +3.3V_L; TestPoint_Pad_D1.0mm
TP8, TP16: GND; TestPoint_Pad_D1.0mm
TP9: USB_DET_R; TestPoint_Pad_D1.0mm
TP10: #5V_FAULT_R; TestPoint_Pad_D1.0mm
TP11: BOOT_R; TestPoint_Pad_D1.0mm
TP12: VBUS_R_RAW; TestPoint_Pad_D1.0mm
TP13: VBUS_R; TestPoint_Pad_D1.0mm
TP14: +5V_R; TestPoint_Pad_D1.0mm
TP15: +3.3V_R; TestPoint_Pad_D1.0mm
U1, U2, U5, U6: AZC199-04S; SOT-23-6; LCSC C2901321
U3, U7: AP2112K-3.3; SOT-23-5; LCSC C3021085
U4, U8: TPS2553DBVR-1; SOT-23-6; LCSC C111738

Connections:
#5V_FAULT_L: R5.1, TP2.1, U4.4 (~FAULT)
#5V_FAULT_R: R14.1, TP10.1, U8.4 (~FAULT)
+3V3_L: C2.2, J3.4, J3.5, J3.6, R9.2, TP7.1, U3.5 (VOUT)
+3V3_R: C5.2, J6.4, J6.5, J6.6, TP15.1, U7.5 (VOUT)
+5V_L: C1.2, TP6.1, U3.1 (VIN), U3.3 (EN), U4.6 (OUT)
+5V_R: C4.2, TP14.1, U7.1 (VIN), U7.3 (EN), U8.6 (OUT)
BOOT_L: J3.16, SW1.1, TP3.1
BOOT_R: J6.16, SW2.1, TP11.1
D+_L: J1.A6 (D+), J1.B6 (D+), J3.11, U1.1 (IO1), U1.3 (IO2)
D+_R: J4.A6 (D+), J4.B6 (D+), J6.11, U5.1 (IO1), U5.3 (IO2)
D-_L: J1.A7 (D-), J1.B7 (D-), J3.10, U1.4 (IO3), U1.6 (IO4)
D-_R: J4.A7 (D-), J4.B7 (D-), J6.10, U5.4 (IO3), U5.6 (IO4)
GND: C1.1, C2.1, C3.1, C4.1, C5.1, C6.1, D1.1 (A1), D2.1 (A1), D3.1 (A1), D4.1 (A1), J1.A1 (GND), J1.A12 (GND), J1.B1 (GND), J1.B12 (GND), J1.S1 (SHIELD), J2.A1 (GND), J2.A12 (GND), J2.B1 (GND), J2.B12 (GND), J2.S1 (SHIELD), J3.2, J3.3, J3.7, J3.9, J3.12, J3.15, J3.MP (Shield), J4.A1 (GND), J4.A12 (GND), J4.B1 (GND), J4.B12 (GND), J4.S1 (SHIELD), J5.A1 (GND), J5.A12 (GND), J5.B1 (GND), J5.B12 (GND), J5.S1 (SHIELD), J6.2, J6.3, J6.7, J6.9, J6.12, J6.15, J6.MP (Shield), Q1.1 (G), Q2.1 (G), Q5.1 (G), Q6.1 (G), R1.2, R2.2, R4.1, R6.1, R7.1, R8.1, R10.2, R11.2, R13.1, R15.1, R16.1, R17.1, R18.1, SW1.2, SW2.2, TP8.1, TP16.1, U1.2 (VN), U2.2 (VN), U3.2 (GND), U4.2 (GND), U5.2 (VN), U6.2 (VN), U7.2 (GND), U8.2 (GND)
HAND_L: J3.1, R9.1
HAND_R: J6.1, R18.2
unnamed: D1.2 (A2), F1.1, Q1.3 (D)
unnamed: D2.2 (A2), F2.1, Q2.3 (D)
unnamed: D3.2 (A2), F3.1, Q5.3 (D)
unnamed: D4.2 (A2), F4.1, Q6.3 (D)
unnamed: F1.2, FB1.2
unnamed: F2.2, FB2.2
unnamed: F3.2, FB3.2
unnamed: F4.2, FB4.2
unnamed: FB1.1, J2.A4 (VBUS), J2.A9 (VBUS), J2.B4 (VBUS), J2.B9 (VBUS)
unnamed: FB3.1, J5.A4 (VBUS), J5.A9 (VBUS), J5.B4 (VBUS), J5.B9 (VBUS)
unnamed: J1.A5 (CC1), R1.1
unnamed: J1.B5 (CC2), R2.1
unnamed: J4.A5 (CC1), R10.1
unnamed: J4.B5 (CC2), R11.1
unnamed: Q2.2 (S), Q3.5 (E2), Q4.3 (D), R3.2, U1.5 (VP)
unnamed: Q3.2 (B1), Q3.3 (B2), Q3.4 (C2), R6.2
unnamed: Q3.1 (C1), Q4.1 (G), R7.2
unnamed: Q6.2 (S), Q7.5 (E2), Q8.3 (D), R12.2, U5.5 (VP)
unnamed: Q7.2 (B1), Q7.3 (B2), Q7.4 (C2), R15.2
unnamed: Q7.1 (C1), Q8.1 (G), R16.2
unnamed: R8.2, U4.5 (ILIM)
unnamed: R17.2, U8.5 (ILIM)
SPLIT_Rx_L: J2.A6 (D+), J2.B6 (D+), J3.14, R20.2, U2.4 (IO3), U2.6 (IO4)
SPLIT_Rx_R: J5.A6 (D+), J5.B6 (D+), J6.13, R19.1, U6.4 (IO3), U6.6 (IO4)
SPLIT_Tx_L: J2.A7 (D-), J2.B7 (D-), J3.13, R19.2, U2.1 (IO1), U2.3 (IO2)
SPLIT_Tx_R: J5.A7 (D-), J5.B7 (D-), J6.14, R20.1, U6.1 (IO1), U6.3 (IO2)
USB_DET_L: J3.8, R3.1, R4.2, TP1.1
USB_DET_R: J6.8, R12.1, R13.2, TP9.1
VBUS_L: C3.2, Q1.2 (S), Q3.6 (E1), Q4.2 (S), R5.2, TP5.1, U2.5 (VP), U4.1 (IN), U4.3 (EN)
VBUS_L_RAW: FB2.1, J1.A4 (VBUS), J1.A9 (VBUS), J1.B4 (VBUS), J1.B9 (VBUS), TP4.1
VBUS_R: C6.2, Q5.2 (S), Q7.6 (E1), Q8.2 (S), R14.2, TP13.1, U6.5 (VP), U8.1 (IN), U8.3 (EN)
VBUS_R_RAW: FB4.1, J4.A4 (VBUS), J4.A9 (VBUS), J4.B4 (VBUS), J4.B9 (VBUS), TP12.1

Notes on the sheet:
3.3V Regulator
1 2 . . . . 16
USB-C Split
ILIM(typ) = 23950/24k = 0.99A
USB-C Host
Current Protection
Matrix Side FPC Connector
Reversed FFC Cable
16 . . . . 2 1

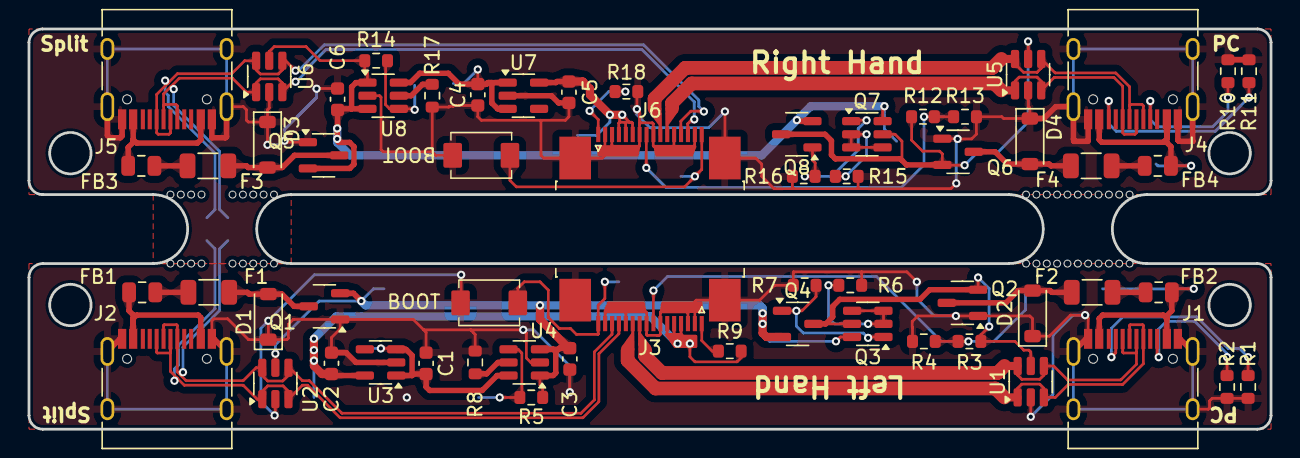
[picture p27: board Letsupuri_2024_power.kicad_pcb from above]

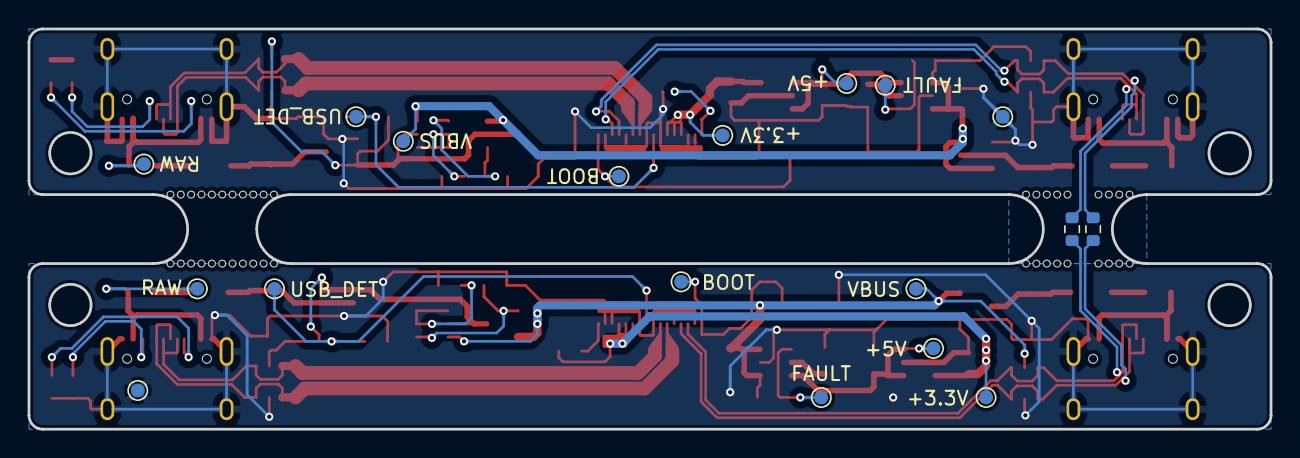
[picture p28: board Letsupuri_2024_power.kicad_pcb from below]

Board: 2 copper layers, 90.0 x 29.0 mm, 80 parts (18 on the bottom side), 47 nets.

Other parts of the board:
mouse-bite-2mm-slot, mouse-bite-2mm-slot#2: VAL**; mouse-bite-5mm-slot
